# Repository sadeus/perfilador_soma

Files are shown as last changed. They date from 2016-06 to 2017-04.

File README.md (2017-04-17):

# Perfilador/Polarimetro SOMA

## Contenido
Se crearon sensores optomecánicos portátiles, para poder medir cambios de los haces de los setups del laboratorio. Todo el marco del proyecto SOMA

### Indice de carpetas
- software: Software para la adquisición y visualización de las mediciones. Acá se efectúa el análisis de los datos obtenidos
- firmware: Código para el uC para el polarimetro/perfilador. Tiene un makefila con los métodos usuales
- circuito: Diseño del circuito impreso
- perfilador: Diseño mecánico del perfilador
- polarimetro: Diseño mecánico del polarimetro
- espectrometro: Diseño del circuito para el espectrómetro (EN PROGRESO)

## Instalación

Para poder instalar y usar el software/firmware de este proyecto es necesario tener [NodeJS](https://nodejs.org/es/):

- Linux, macOS: Instalación por manejador de paquetes, [aquí](https://nodejs.org/es/download/package-manager/)
- Windows: Descargar binario de la página oficial

En una command prompt o terminal escribir lo siguiente para instalar dependencias

```npm install```

Esto instala las dependencias de firmware y software. Para obtener ayuda de los comandos disponibles ejecutar

```npm run```

### Lista de comandos
- `npm run ip`: abre el puerto serie creado al conectar el uC y obtiene la ip del dispositivo
- `npm run start`: inicia el servidor web del software de adquisición. Por defecto se entra en un browser en http://localhost:9000
- `npm run compile`: compila el firmware. Para compilar el firmware, por ahora, es necesario logearse con `npm run login` y una cuenta de [particle.io](http://build.particle.io)
- `npm run upload`: Actualiza el firmware del uC por USB. Es necesario tener el uC en modo DFU (ver [acá](https://docs.particle.io/guide/getting-started/modes/photon/#dfu-mode-device-firmware-upgrade-))

## Dependencias

### Software
- Python v3.5.0
- Numpy v1.11.3
- Pandas v0.19.2
- Matplotlib v2.0.0
- Scipy v0.18.1
- Flask v0.12
- Web browser (Firefox, Chrome, Safari, _no funciona en IE_)

### Firmware
Para compilar, flashear y escuchar el puerto Serie del uC es necesario tener:
- NodeJS v6.0
- Particle-cli v1.21.0
- readline-sync (para interfaz interactiva)

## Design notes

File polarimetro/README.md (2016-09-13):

# Polarímetro
## Proyecto SOMA

### Especificaciones

#### Mecánica
* Dimensiones: 
* Velocidad de adquisición: 10 mediciones/s
* Forma de fotodiodo: TO-5

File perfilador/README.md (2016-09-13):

# Perfilador de haz
## Proyecto SOMA

### Especificaciones
#### Mecánicas
* Dimensiones sin prolongación: 40x40x60 mm
* Dimensiones de prolongación: 50 mm desde centro del soporte, 8x20 mm 
* Diametro máximo de haz perfilable: 10 mm 
* Velocidad de adquisición: 40 perfiles/s
* Forma de fotodiodo: TO-5

#### Software embebido
* Microcontrolador: Particle Photon
    - STM32F205 120Mhz ARM Cortex M3
    - 1MB Flash
    - 128KB RAM
    - Broadcom BCM43362 Wi-Fi chip. 802.11b/g/n 2,4GHz
* Implementación en C++

#### Software PC
* Adquisición cada 1s de 40 perfiles
* Python v3.x
    - Numpy
    - Scipy
    - Matplotlib
    - PyQT

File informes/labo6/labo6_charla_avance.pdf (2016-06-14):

## Construcción de un perfilador de haz portátil automático

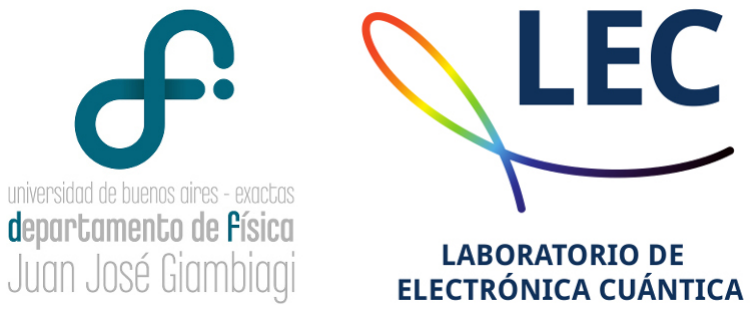
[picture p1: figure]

Estudiante: Sebastián Schiavinato Director: Dr. Hernán E. Grecco Codirectora: Dr. Andrea V. Bragas

Laboratorio 6, DF, FCEyN, UBA

Noviembre 19, 2015

## Objetivo del proyecto

Objetivos de laboratorio 6:
- Diseñar y construir un perfilador portátil y de fácil reproducción capaz de caracterizar el haz en diferentes setups ópticos.
- Diseñar y construir un espectrómetro portátil para aplicaciones del LEC, adaptado a los diferentes setups del laboratorio.

## Motivación del proyecto

Mucho es el tiempo desperdiciado en el laboratorio armado y desarmando el setup, alineando cada etapa.

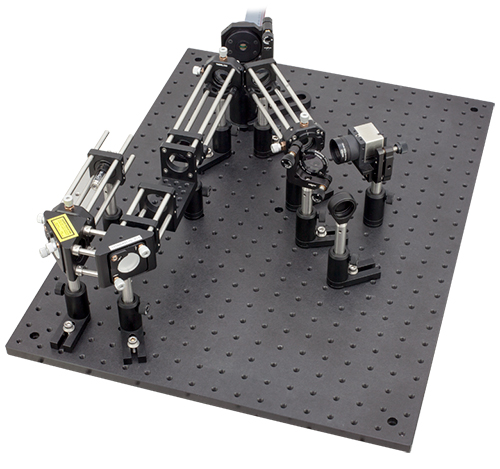
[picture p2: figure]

Caracterizar haces de fuentes con-lleva
- Perfil espacial. Divergencia
- Perfil espectral y temporal
- Polarización

## Concepto del perfilador

Funcionamiento general de un perfilador
- Se corta el haz con un filo móvil (en general con un
tornillo micrométrico),
recolectando el haz.
- Se usan sensores
económicos, integradores del haz obturado.

## Concepto del perfilador

Para haces gaussianos (la mayoría), el perfil de intensidades, es decir la integral del perfil, es la función error

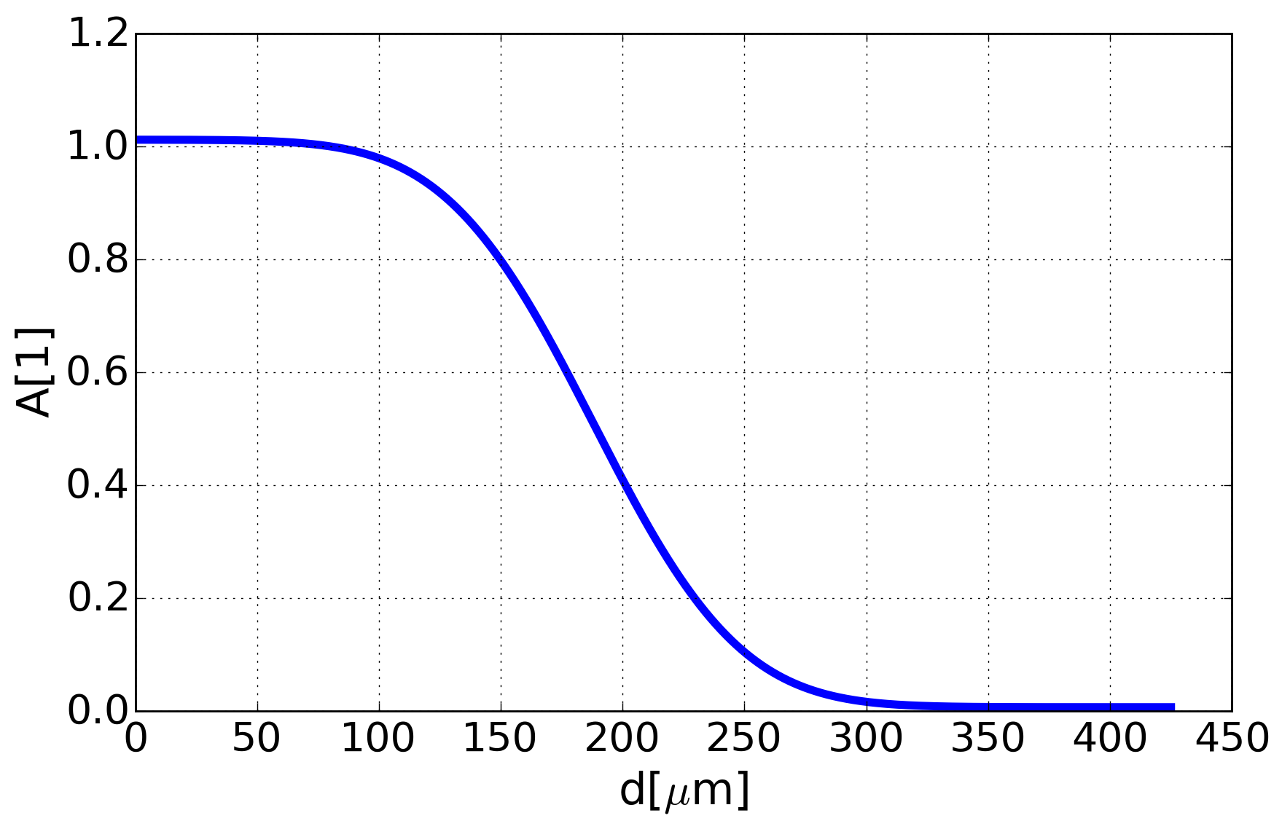
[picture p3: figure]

## Concepto del perfilador

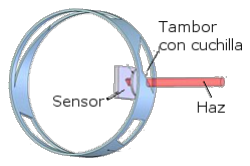
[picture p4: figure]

Propuesta inicial:
- Tambor giratorio, capaz de obturar automáticamente
- Sensor de luz integrador, tipo fotodiodo o medidor de potencia
- Adquisición en tiempo real de los cambios del haz.

## Diseño mecánico

Premisas mecánicas del perfilador:

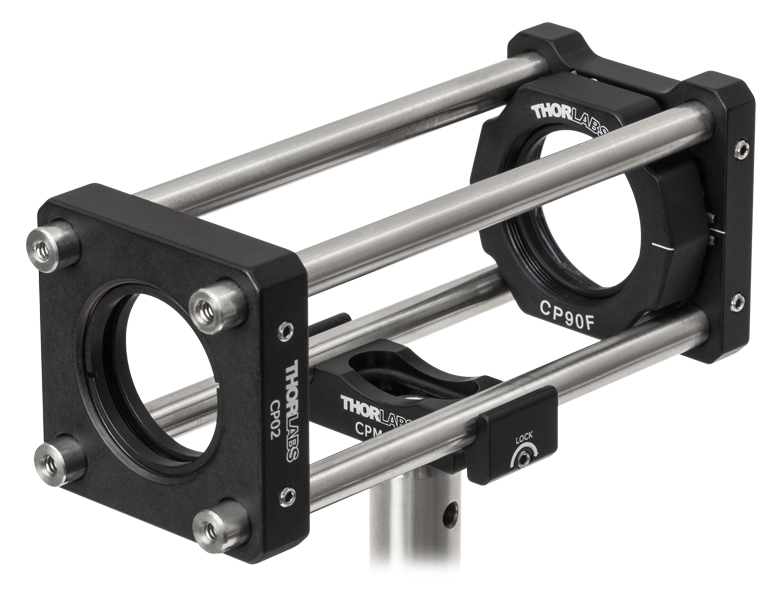
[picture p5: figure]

- Se debe poder insertar en el sistema Cage de ThorLabs, de 30mm. A 50mm de la mesa
- El tambor debe tener una velocidad que permita
actualización en tiempo real.

## Diseño mecánico

Diseño del tambor

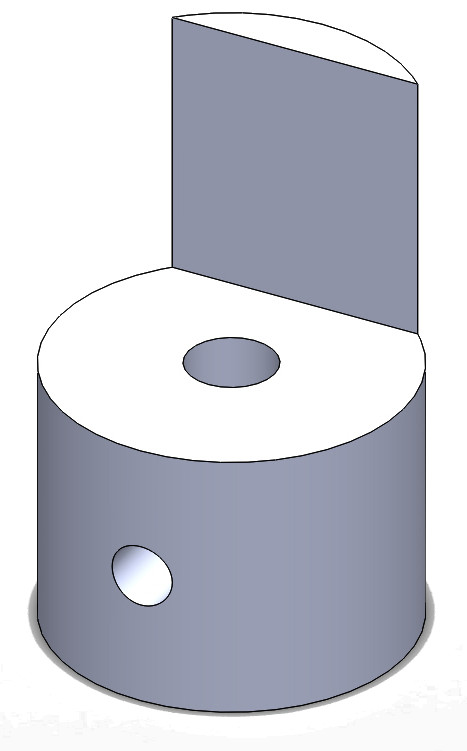
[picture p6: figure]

- Cilindro de 20mm de diametro
- Fácil de ubicar en el Cage
- Proyección axial, permite obturar el haz.
- Fácil prototipado con impresora 3D.

## Diseño mecánico

El motor se determinó con las siguientes premisas
- Debe ser fácil de controlar la velocidad. Descartados motores de escobillas, que requieren retroalimentación.
- Debe ser rápido, alcanzando 24 revoluciones por segundo si se puede. Descartado servomotores, no alcanzan las 2 revoluciones por segundo.
Se eligen motores paso a paso.
- Motor modelo NEMA 17 (1,8◦
, máx 3000PPS, 4kg cm).

## Diseño mecánico

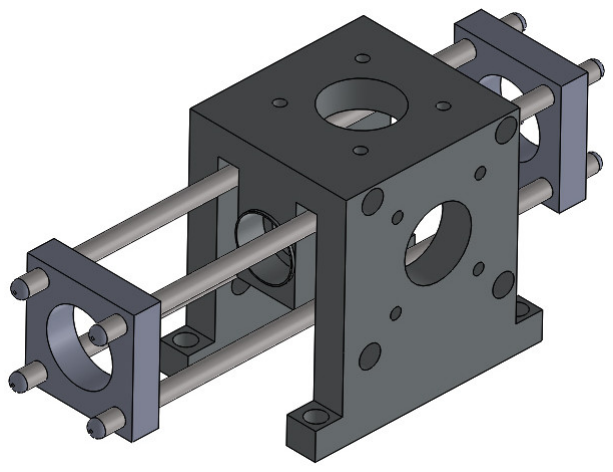
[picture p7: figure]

- Diseño auto-portante, no se necesita ningún agregado.
- Permite adaptarse al Cage y a otros entornos de trabajo.
- Permite medir el haz en
varias direcciones.

## Diseño de electrónica de adquisición

Electrónica digital (microcontrolador) de uso general, adaptada a la adquisición de un sensor de luz (fotodiodo)

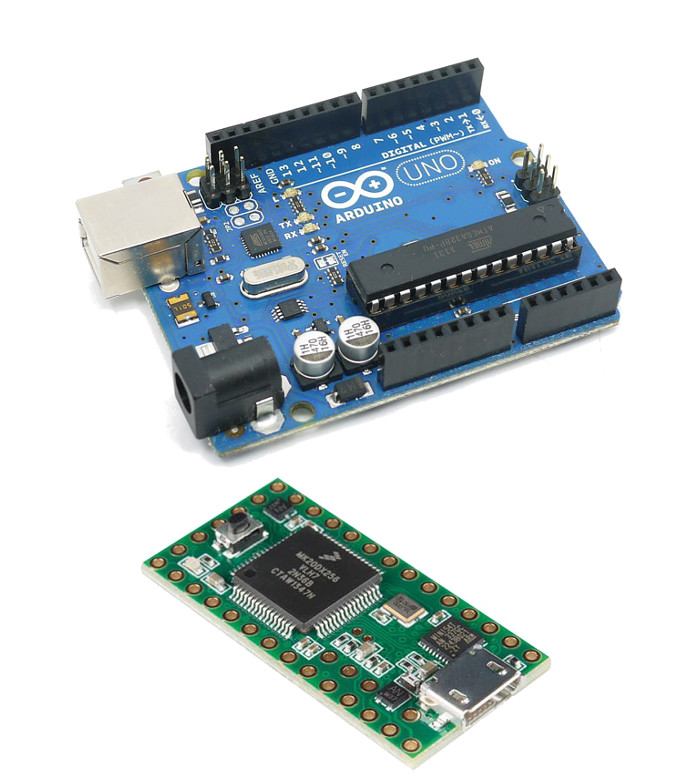
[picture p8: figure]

- Arduino UNO: Barato,
sencillo. CPU 16MHz y
2KiB RAM. ADC a 10ksps.
- Teensy v3.1: CPU 96MHz, y 64KiB RAM. ADC a 1Msps.
Tipicamente 100kmps.

## Diseño de electrónica de adquisición

Circuito resultante, con integrado driver (Pololu A4988) del motor

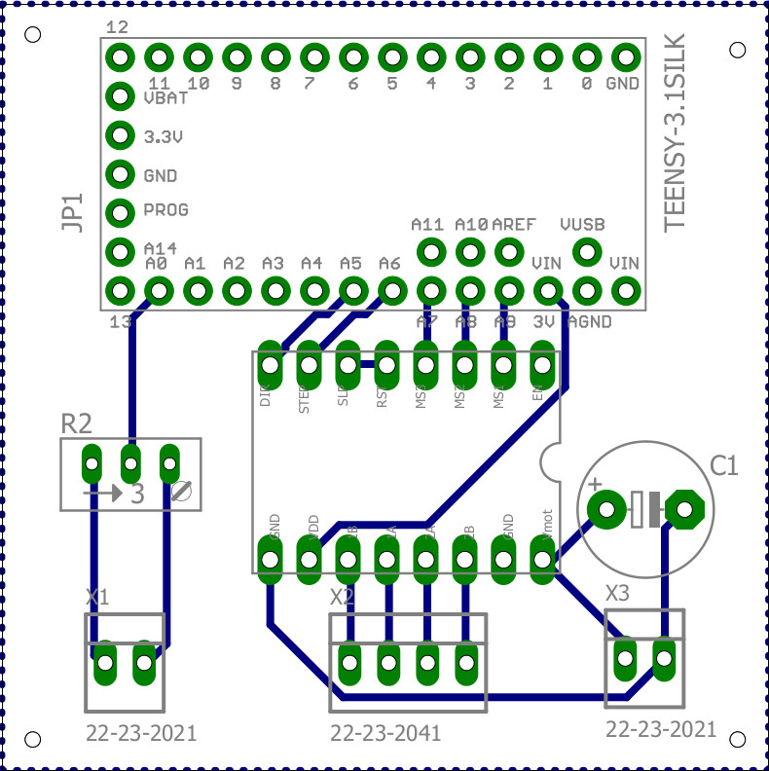
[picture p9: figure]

- Permite mover motores
hasta 2A por fase.
- Adquiere corriente del
fotodiodo en resistencia
variable por el usuario
- Adquiere 100ksps de la señal analogica.
- Permite adquirir a la
velocidad máxima de
12RPS, limitación del
motor, es decir adquirir
24 perfiles por segundo.

## Analisis de datos

La computadora es encargada del análisis automático de los datos transmitidos. A partir de una serie de datos

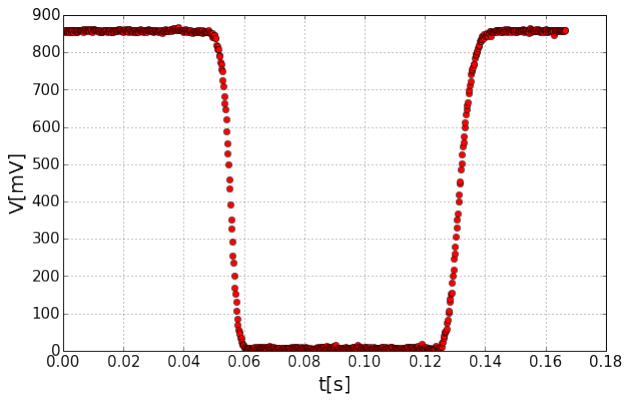
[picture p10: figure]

## Analisis de datos

Se ajusta automáticamente los datos con un algoritmo de procesamiento de señales propio.
- Tamaño del haz inferido del ajuste y la velocidad del
motor, con el error de
propagación
- Diferencia entre perfiles debido a problemas
mecánicos de la pieza
plástica.

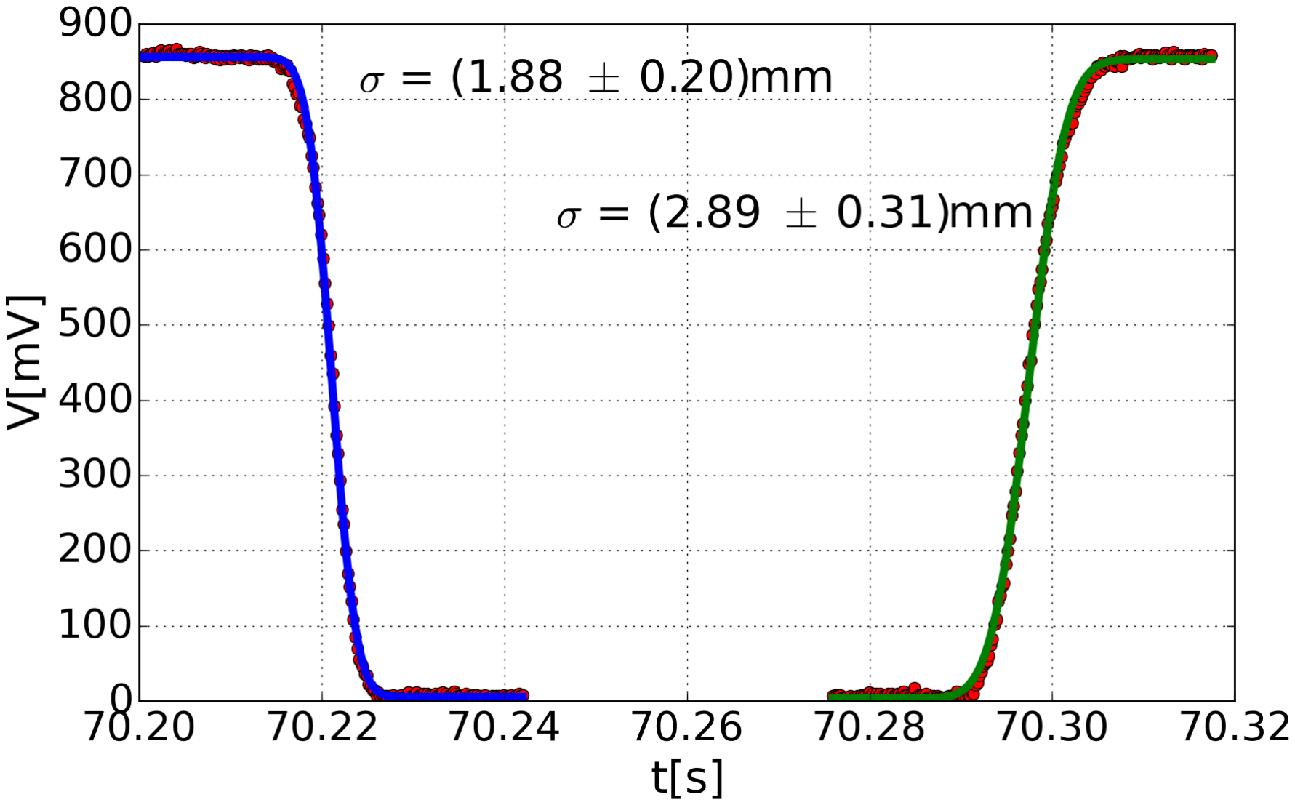
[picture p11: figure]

## Proyecto SOMA (Sistema de OptoMecánica Abierta)

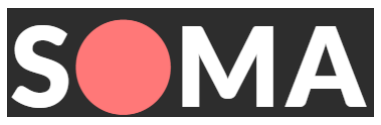
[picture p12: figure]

- Plataforma abierta de instrumental opto-mecánico
- Diseño con énfasis en la reproducibilidad, con tecnología de impresora 3D o mecanizado automático.
- Electrónica libre, controlada por software creado con tecnologías libres.

Página del proyecto: http://lec.df.uba.ar/soma

## A completar

- Mecanizado de las piezas metálicas
- Terminado final del perfilador
- Diseño y construcción del espectrómetro, a partir del circuito Hamammatsu C12666MA

## Objetivos de Laboratorio 7

Estos dispositivos van a ser utilizados durante laboratorio 7 en los siguientes proyectos:
- Mejora de la resolución del SPIM mediante la optimización del perfil del haz
- Caracterización del espectro de emisión de nanolamparas de Lantánidos

# Gracias

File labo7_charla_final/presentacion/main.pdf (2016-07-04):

## Determinación de características ópticas del SPIM para la medición de anisotropía de muestras biológicas


Estudiante: Sebastián Schiavinato Director: Dr. Hernán E. Grecco Codirectora: Dr. Andrea V. Bragas

Laboratorio 6 y 7, DF, FCEyN, UBA

Julio 5, 2016

## Motivación del proyecto

En el Laboratorio de Electrónica Cuántica (LEC) se dispone de un microscopio SPIM

- Utiliza muestras con fluoroforos
- Con una hoja de luz
(lightsheet) ilumina un plano de la muestra por vez
- Disminuye el photobleaching (blanqueo de los flouroforos)
- Permite recostruir una imagen en 3D de la muestra

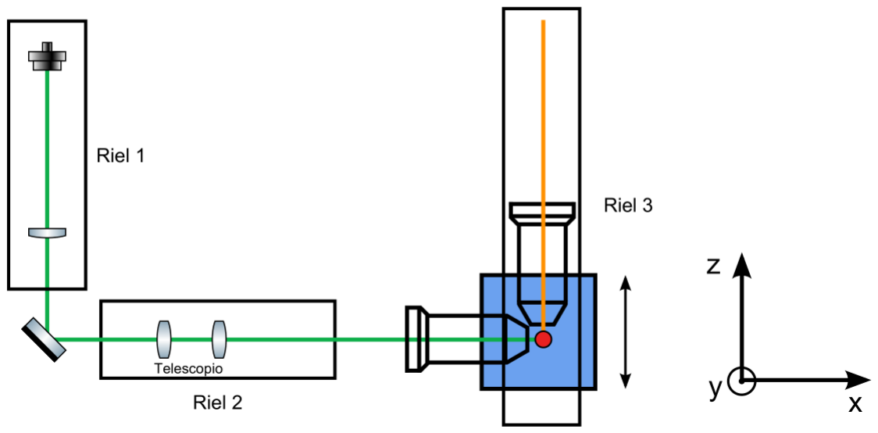
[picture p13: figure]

## Motivación del proyecto

La construcción de este microscopio requiere determinar

- Perfil del haz, que cambia el
tamaño de la hoja del haz
- Espectro del haz, determina los flouroforos a utilizar
- Polarización del haz, que si es lineal permite hacer mediciones
de anisotropía de los fluoroforos

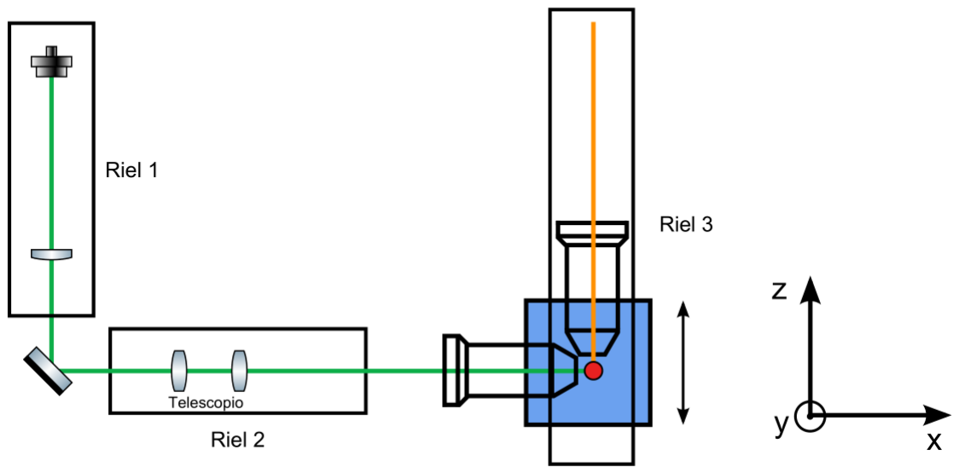
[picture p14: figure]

Para calibrar el SPIM,se construyó el siguiente instrumental portátil
- Perfilador
- Polarimetro

## Concepto del perfilador

- Determinar el perfil especial del haz en un plano
- Al desplazarse permite
determina la divergencia del haz.
- Perfiladores con cámaras CCD. Sensores muy caros
- Perfiladores integradores. Complejidad mecánica

## Concepto del perfilador

Para haces gaussianos (la mayoría), el perfil de intensidades, es decir la integral del perfil, es la función error


## Concepto del polarizador

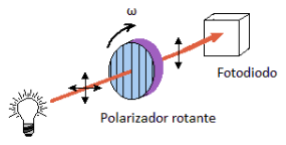
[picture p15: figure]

- Permite determinar eje mayor y eje menor de polarización eliptica.
- Permite identificar polarización circular.
- Depende de la precisión de rotación del motor, pero puede mejorarse con mecánica adecuada.

## Concepto del polarizador

Ley de Malus

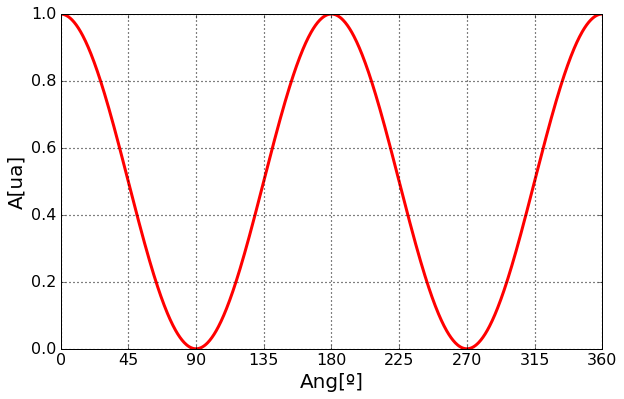
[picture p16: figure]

α =

máx − mín
máx + mín =

1 | si lineal
0 | si circular
(0, 1) si eliptica

## Perfilador en Laboratorio 6

Piezas mecánicas del perfilador

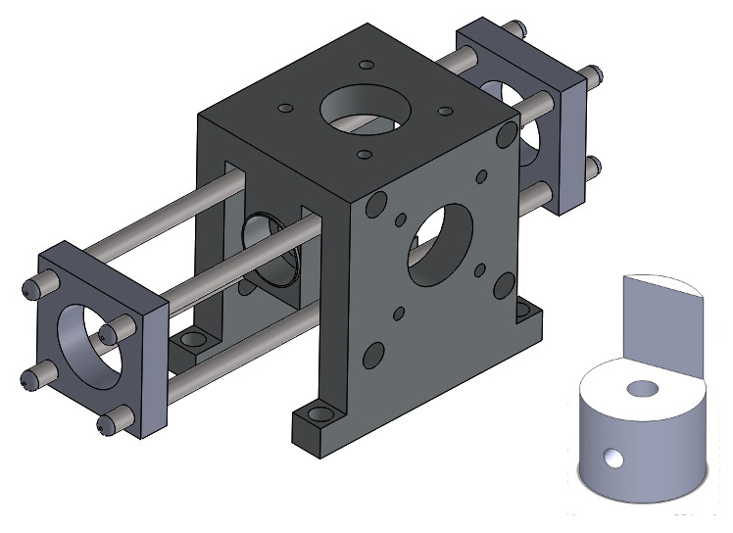
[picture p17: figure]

- Diseño autoportante.
- Tambor de perfilación permite medir en sistema Cage de
Thorlabs. Permite medir
divergencias importantes
- Tambor impreso en 3D.
- Motor paso a paso NEMA 17. 200 pasos por vuelta. Máximo 15rps.

## Perfilador en Laboratorio 6

Electrónica de adquisición

- uC Teensy v3.2. CPU 96MHz, y 64KiB RAM. ADC 1Msps max.
- Pololu A4988. Motores hasta 1.5A por fase
- Buffer de puerto serie de 1200 datos
- Software de ajuste en continuo cambio. Hecho en Python
- Máxima adquisición de 12 perfiles por segundo, limitación del uC/Software.


## Mediciones de calibración

Mediciones de calibración

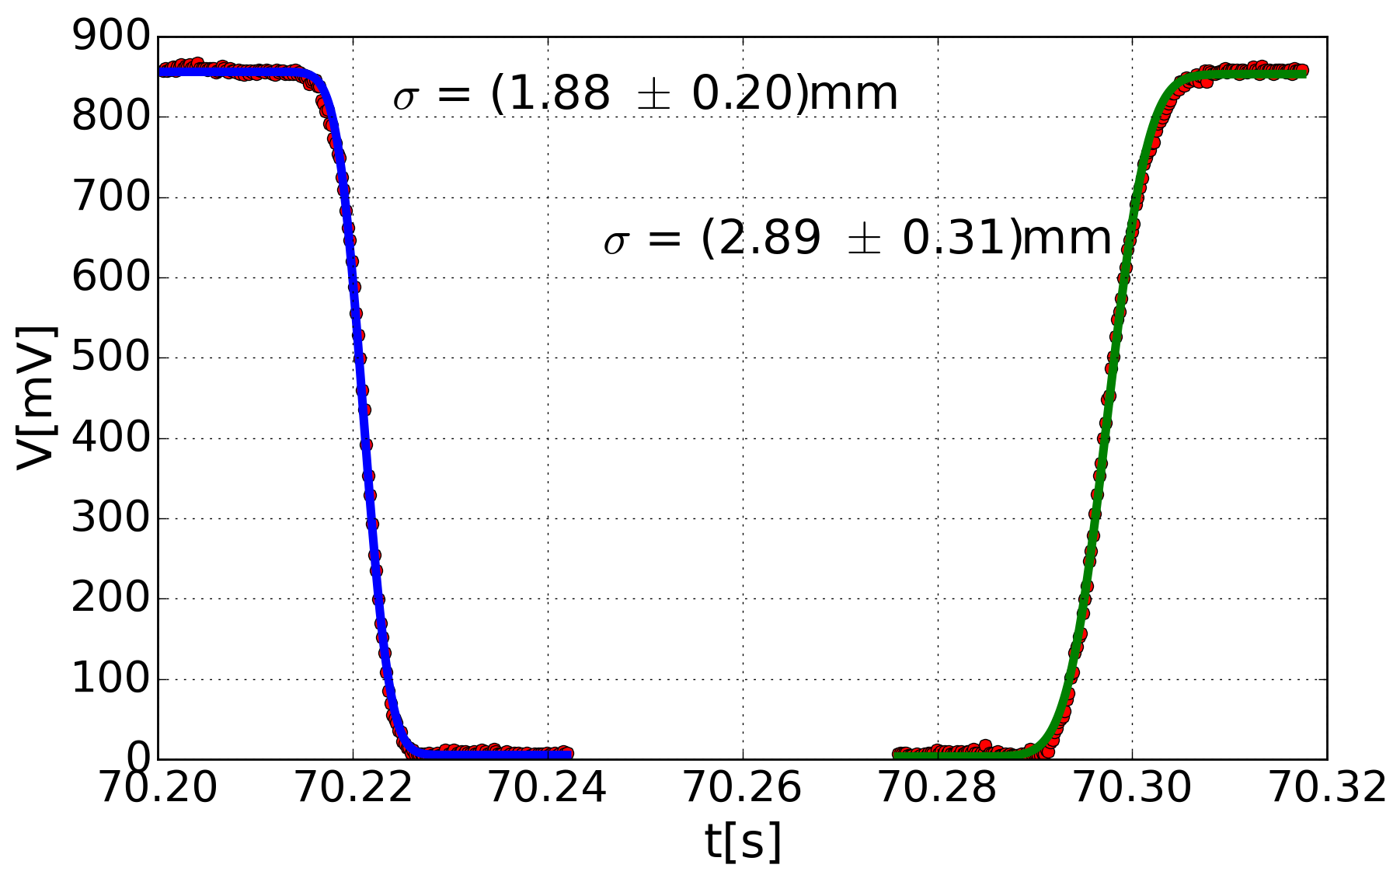
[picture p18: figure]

- Medición a salida de
colimador F220FC.
- Diferencia apreciable de tamaño de haz entre
transiciones.
- Es de origen mecánico,
soporte no ajusta
correctamente el motor

## Mediciones de calibración

Mediciones de calibración

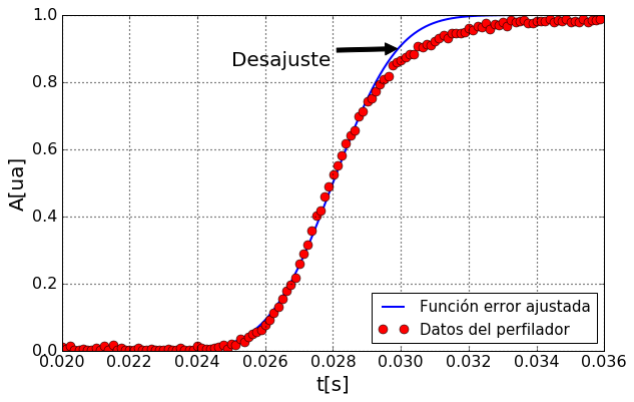
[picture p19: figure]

- Desajuste entre función error y datos al
desobturar haz.
- Fotodiodo con
resistencia de carga
enorme genera respuesta
en frecuencia pobre.
- Es necesario amplificar
señal del fotodiodo

## Perfilador en Laboratorio 7

Primera iteración mecánica

- Soporte adosable a la
mesa óptica por perros.
Facil colocación
- Motor encastrado en
soporte. No hay
artefactos mecánicos
- Tambor de metal con
superficie no reflectante
- No permite medir
fácilmente en el otro eje. Habrá otra iteración

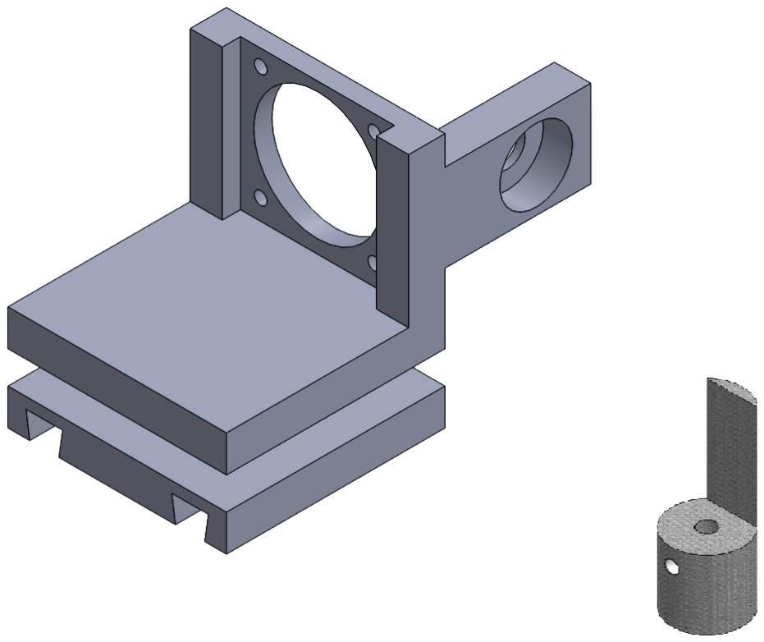
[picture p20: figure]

## Perfilador en Laboratorio 7

Segunda iteración mecánica.

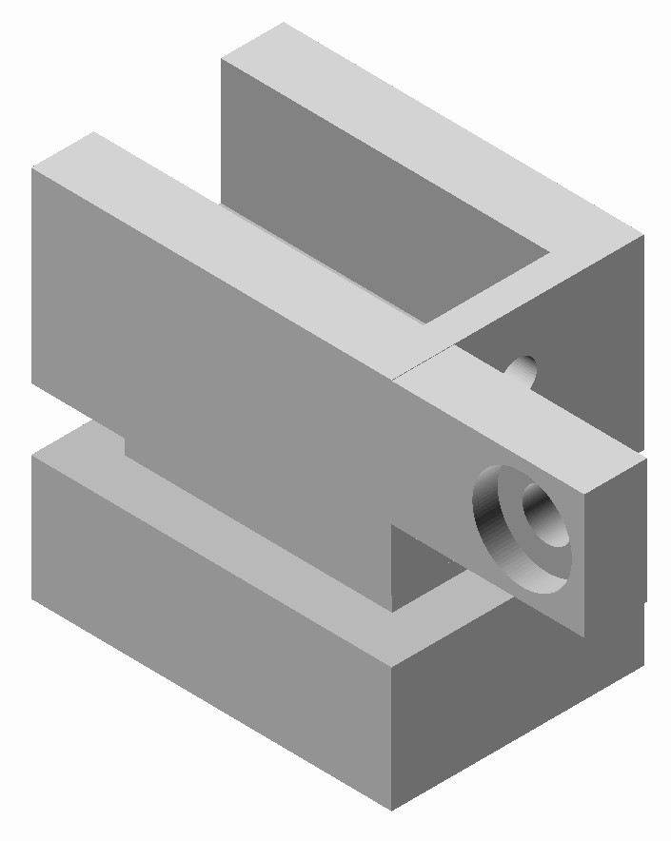
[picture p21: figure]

- Motor NEMA 8, reduce un
500 % el tamaño.
- Soporte fácil de colocar sobre la mesa óptica y sobre un soporte en altura
- Tambor reimpreso en plástico

## Mecánica del polarimetro

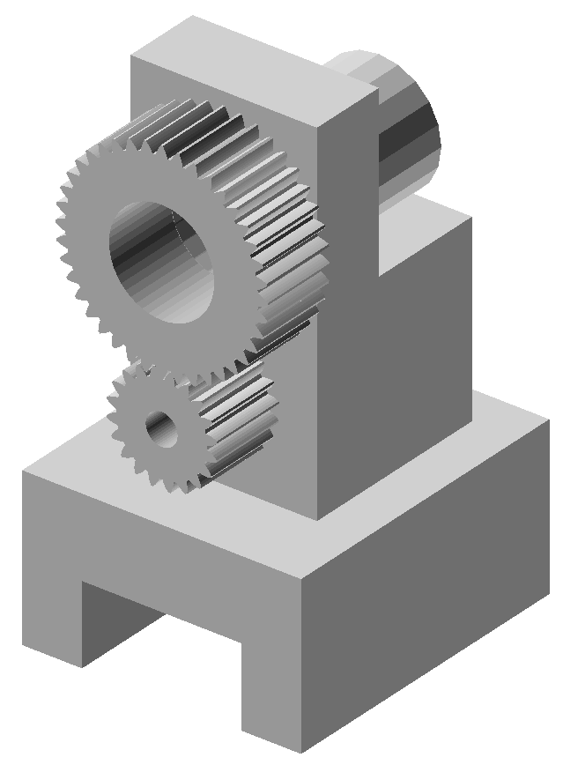
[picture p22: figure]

- Motor NEMA 8 mueve el
engranaje inferior paso a paso
- Utiliza electrónica creada para el perfilador. Mide en cada paso del motor
- Hecho con impresión 3D en plástico

## Electrónica de adquisición

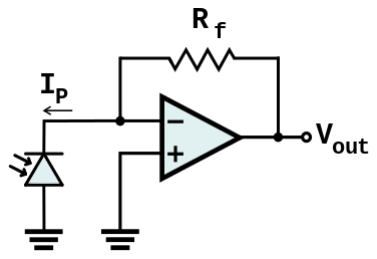
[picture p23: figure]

- Se mide con amplificador de corriente Standford SR750 y se observa mejoras substanciales
- Implementado amplificador de transimpedancia con fotodiodo no polarizado.
- Mejor respuesta en frecuencia y ajusta correctamente una
función error.

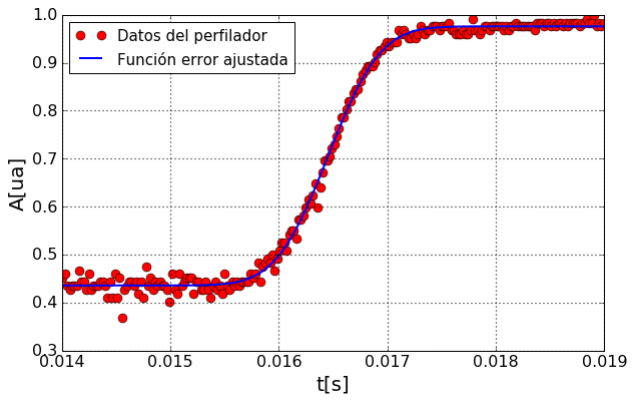
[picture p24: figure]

## Calibración de amplificador


- Amplificador con LM358.
Con fuente simple
- Respuesta al escalón de 0,4V µs

−1
. 4 veces más
grande de la necesaria
- Rango lineal bastnate
amplio, pero no acusa
corriente nula. Se puede
buscar otro amplificador.
Suficiente para la
amplicación

## Generación de sensores portátiles


Spark Photon
- ARM Cortex M3 120MHz con stack WiFi.
- 128KiB RAM y 1MiB FLASH
- Programación en la nube, permite actualizaciones OTA.
- API de programación más poderosa. C++ por defecto
- Software implementado con licencia libre, puede ser
adaptado

## Generación de sensores portátiles

Resultados con este uC/Software


- Se pudo mover el motor hasta 30RPS. PWM mejor implementado
- Adquisición de datos (del uC) cada 10µs o 100ksps. Más de lo necesario
- Conexión TCP ya resuelta, cada 0,1s se obtiene 4000 datos.
- Software de adquisición hecho enteramente en Python, libre, con interfaz de usuario gráfica

## Mediciones con el perfilador


Calibración del instrumento, medición del colimador F280FC del SPIM

- Inicio del riel:
σ = (3, 03 ± 0, 15) mm
- Fin del riel:
σ = (3, 02 ± 0, 18) mm

## Mediciones con el perfilador

Medición manual del colimador F280FC del SPIM


## Mediciones con el perfilador


Haz en el telescopio del SPIM

Medición a
d≈80 mm del fin del telescopio σ1 = (0, 55 ± 0, 02) mm
σ2 = (2, 11 ± 0, 05) mm

## Mediciones con el polarimetro

Calibración de láminas polarizadoras

- Con dos polarizadores móviles se puede terminar los
parámetros del material
polarizador
- El plástico usado tiene la siguiente matriz de transmisión
0, 5 | 0
0 | 2 × 10⁻⁶


- Permite polarizar, pero elimina un %50 de la señal en el
máximo.

## Mediciones con el polarimetro


Medición de polarización par láser azul DHOM-M-473 Antes de la fibra óptica

máx − mín
máx + mín = (0,83 ± 0,39)

Después de la fibra óptica

máx − mín
máx + mín = (0,83 ± 0,31)

## Conclusiones

Del polarizador
- El perfilador mide exitosamente el haz, con un error del %5, comparable con la medición manual
- Se pudo caracterizar el haz a salir de la fibra y en el telescopio correctamente
- El perfilador fue capaz de medir la divergencia
con solo un set de mediciones.
- Para medir la salida del telescopio habrá que diseñar un perfilador más compacto.

## Conclusiones

Del polarimetro
- La lámina polarizadora utilizada está lejos de ser un polarizador perfecto, pero es funcional a la aplicación
- Se midió la polarización antes de acoplar en fibra y después de acoplar en fibra y no se observó cambio de polarización
- Esta medición es de importancia fundamental para medir anisotropía de flouroforos en el SPIM

## Proyecto SOMA (Sistema de OptoMecánica Abierta)


- Plataforma abierta de instrumental opto-mecánico
- Diseño con énfasis en la reproducibilidad, con tecnología de impresora 3D o mecanizado automático.
- Electrónica libre, controlada por software creado con tecnologías libres.

Página del proyecto: http://lec.df.uba.ar/soma

# Gracias

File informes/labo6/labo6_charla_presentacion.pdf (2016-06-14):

## Construcción de instrumental optomecánico portatil


Sebastián Schiavinato

Laboratorio 6, DF, FCEyN, UBA

September 15, 2015

## SPIM (Single Plane Ilumination Microscope)


- Se crea un haz en forma de hoja (lightsheet).
- El objetivo del microscopio está a 90◦
- Moviendo la muestra
(sumergida en agua) se
activan diversos planos de fluoforos y se reconstruye la imagen en 3D de la muestra.

## Problemas, Caraterización

Caracterizar un haz de luz conlleva

- Perfil espacial
- Divergencia
- Perfil espectral y temporal
- Polarización


Mucho es el tiempo desperdiciado en el laboratorio armado y desarmando el setup, alineando cada etapa.

## Objetivos

El objetivo de este trabajo de Laboratorio 6 es diseñar y construir un perfilador y un espectrómetro portátil y de pequeñas dimensiones, que permita utilizarlos de forma rápida en los setups usuales del LEC y de los laboratorios de óptica.


## Perfilador

Funcionamiento general de un perfilador
- Se corta el haz paso a paso, recolectando el haz.
- Sensores más económicos.


Propuesta de este laboratorio:
- Tambor giratorio con
ranuras.
- Adquisición en tiempo real de los cambios del haz.

## Espectrometro


- Separación de luz en el plano del CMOS lineal
- Serialización de señal captada por el CMOS integrada

## Proyecto SOMA (Sistema de OptoMecánica Abierta)


- Plataforma abierta de instrumental opto-mecánico
- Diseño con énfasis en la reproducibilidad, con tecnología de impresora 3D o mecanizado automático.
- Electrónica libre (Arduino), controlada por software creado con tecnologías libres.

Página del proyecto: http://lec.df.uba.ar/soma

## Objetivos a futuro, Laboratorio 7

Estos dispositivos van a ser utilizados durante laboratorio 7 en los siguientes proyectos:
- Mejora de la resolución del SPIM mediante la optimización del perfil del haz
- Caracterización del espectro de emisión de nanolamparas de Lantánidos

## Factibilidad

- Diseño reproducible de forma simple para cualquier laboratorio
- Electrónica y sistema de adquisición de datos libres.
- Extensa documentación y experiencia en el laboratorio.
- Financiamiento por proyecto ANPCyT PICT-2013-1301

# Gracias

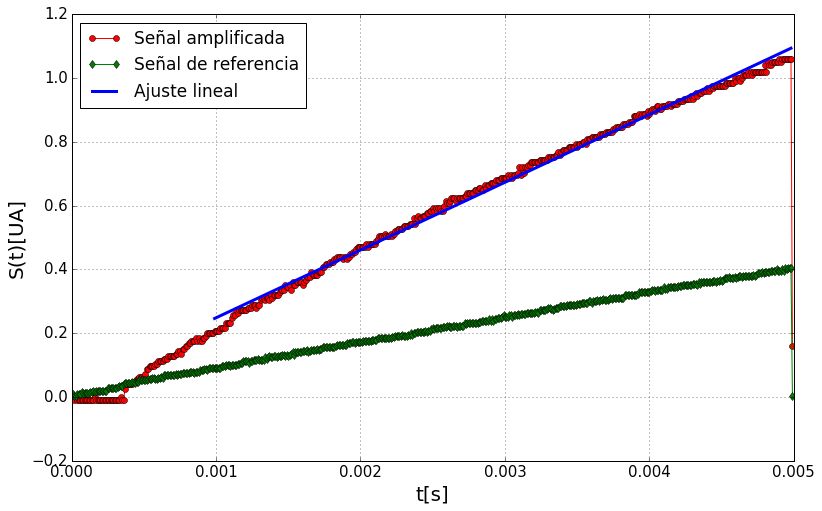
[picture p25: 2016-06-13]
circuito/design/analisis_amp/analisis/lin_amp.png

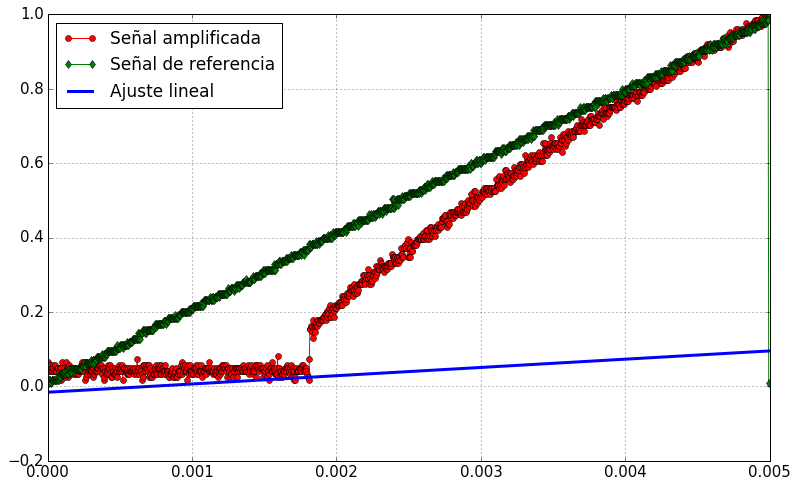
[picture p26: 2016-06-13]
circuito/design/analisis_amp/analisis/led_rojo_rampa_offset.png

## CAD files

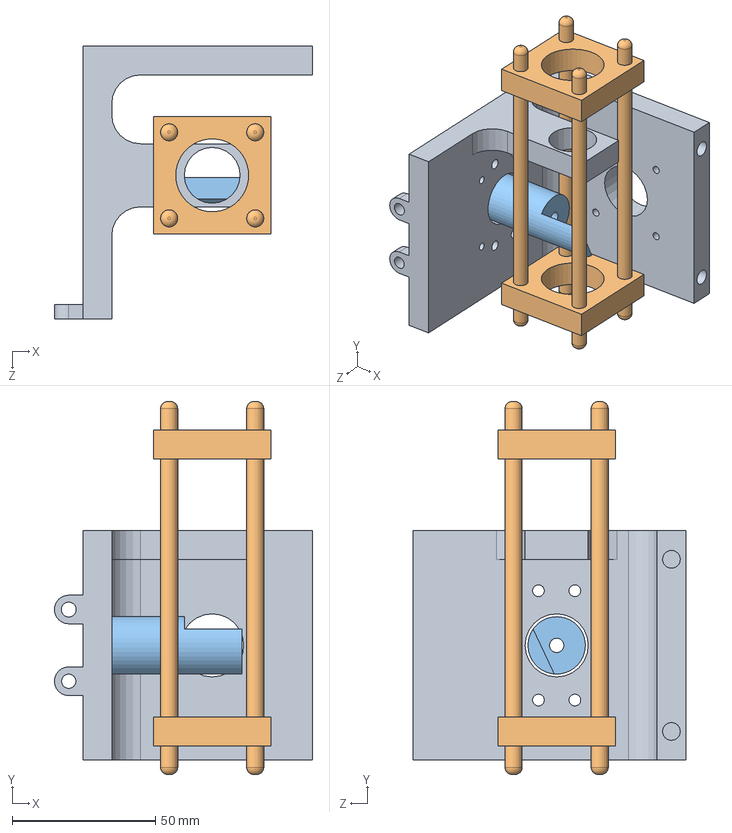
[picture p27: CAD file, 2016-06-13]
perfilador/mecanica/nema17/ensamblaje.SLDASM
90.0 x 130.0 x 95.0 mm
soporte_v2
cage
tambor_v2

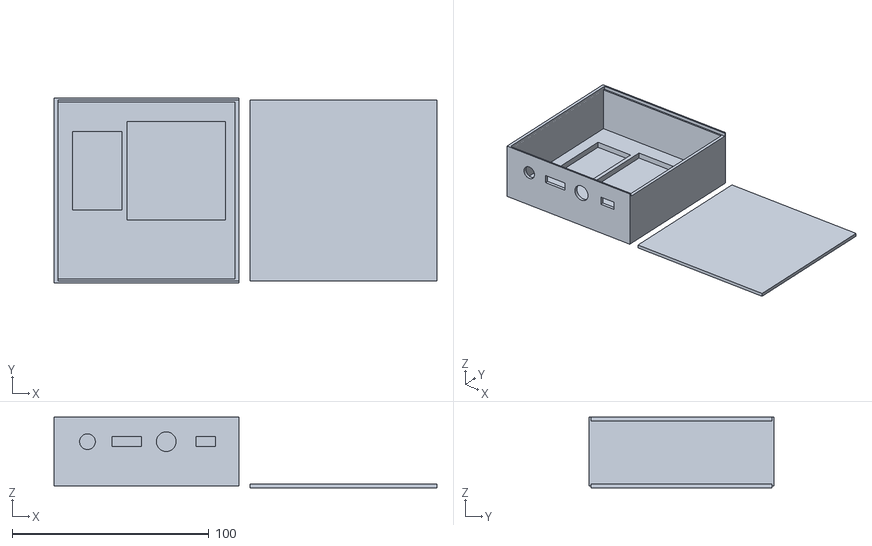
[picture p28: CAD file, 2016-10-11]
circuito/carcasa.stl
194.5 x 94.0 x 36.0

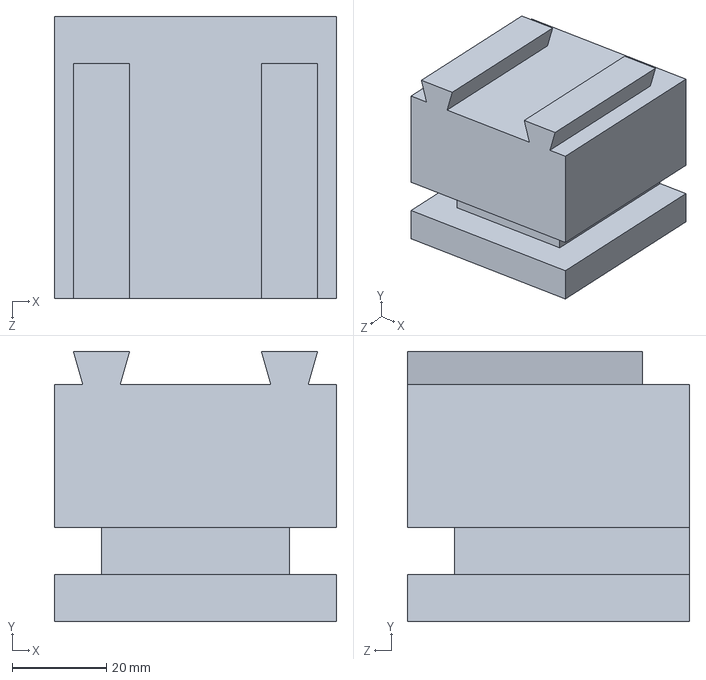
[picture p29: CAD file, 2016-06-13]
perfilador/mecanica/nema17/encastre/soporte_base_50_5.SLDPRT
60.0 x 57.5 x 60.0 mm

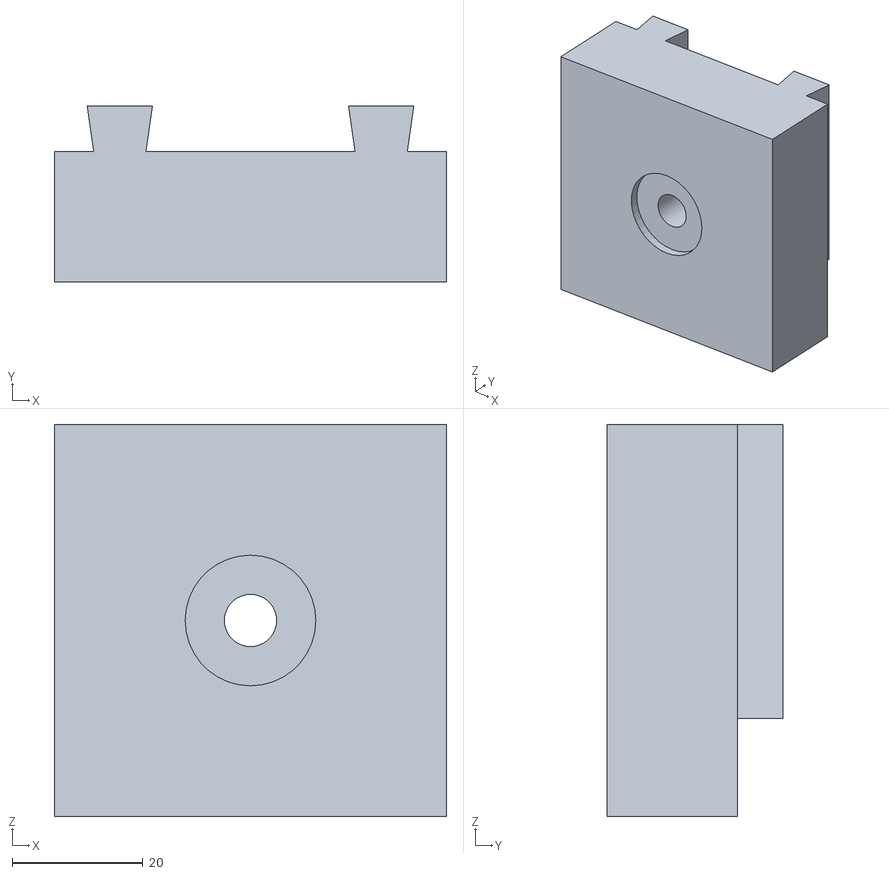
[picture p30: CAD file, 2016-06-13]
perfilador/mecanica/nema17/soporte/soporte_base_poste.stl
60.0 x 27.0 x 60.0

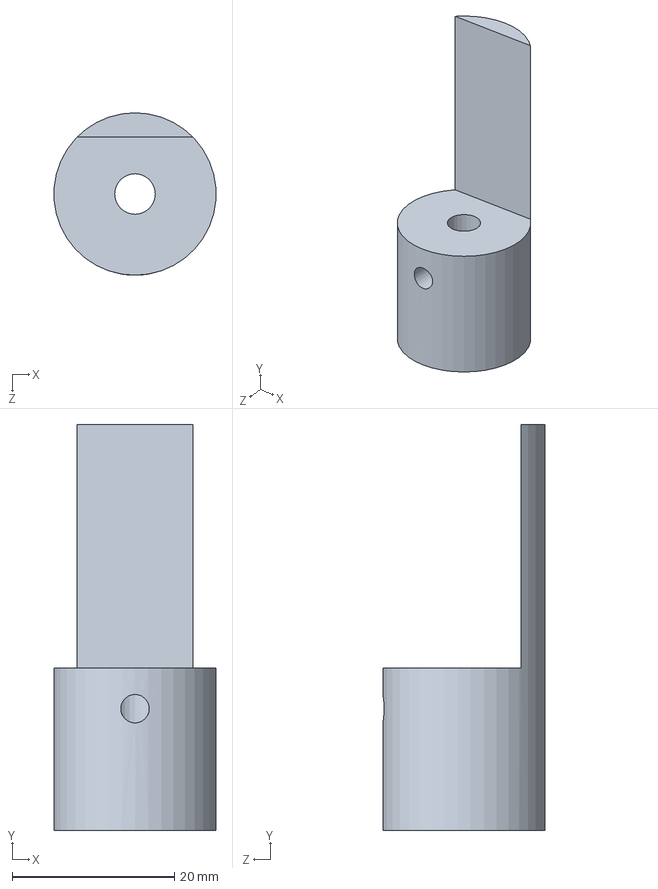
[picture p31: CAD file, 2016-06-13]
perfilador/mecanica/nema17/tambor/tambor_v3.sldprt
19.9 x 50.0 x 20.0 mm

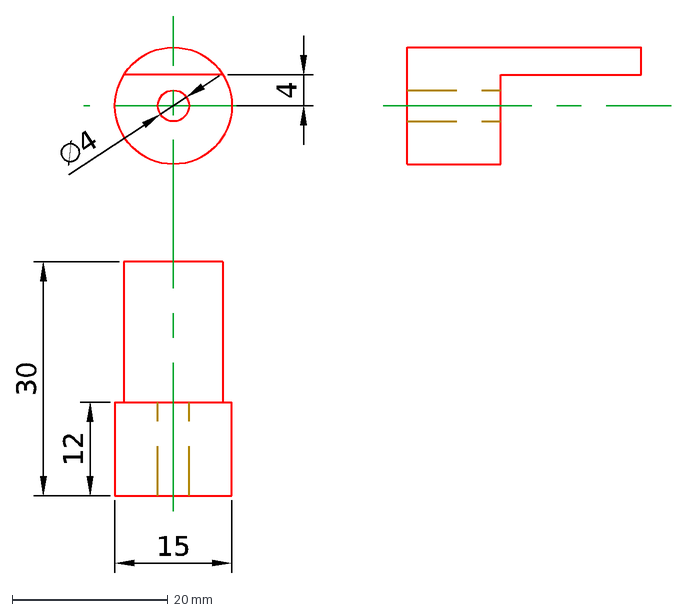
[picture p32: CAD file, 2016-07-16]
perfilador/mecanica/nema8/tambor_perfilador.dxf
15
30
12
4
∅4

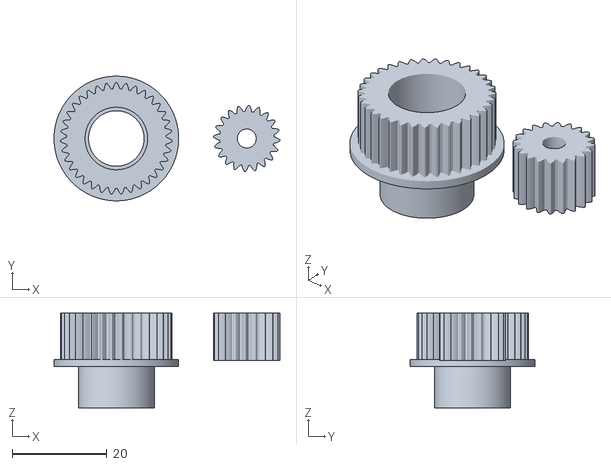
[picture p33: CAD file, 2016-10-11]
polarimetro/design/engranajes.stl
47.6 x 26.3 x 20.0

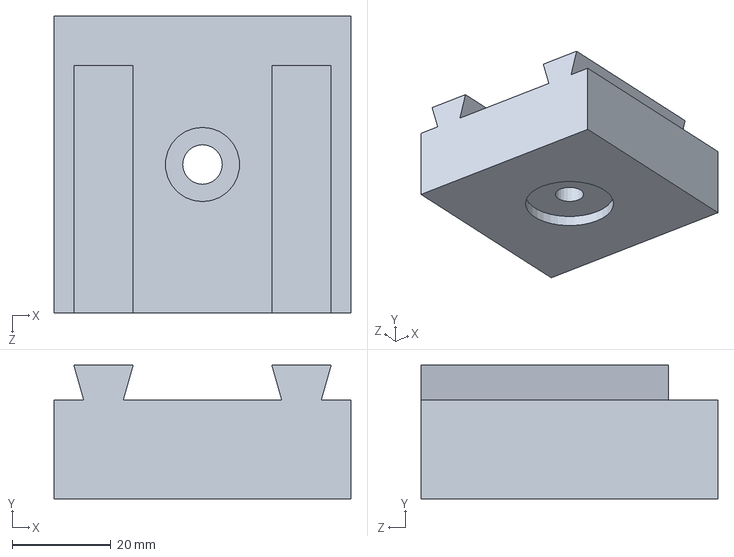
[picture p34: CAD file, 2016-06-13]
perfilador/mecanica/nema17/encastre/soporte_base_poste.SLDPRT
60.0 x 27.0 x 60.0 mm

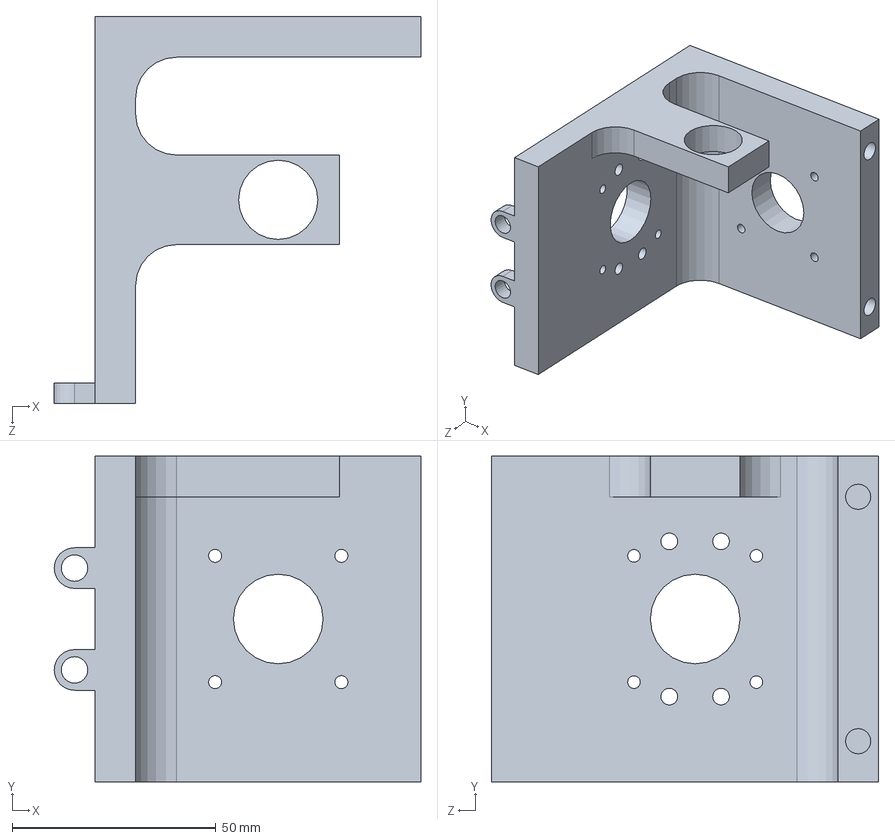
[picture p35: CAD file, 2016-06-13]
perfilador/mecanica/nema17/soporte/soporte_v2.sldprt
90.0 x 80.0 x 95.0 mm

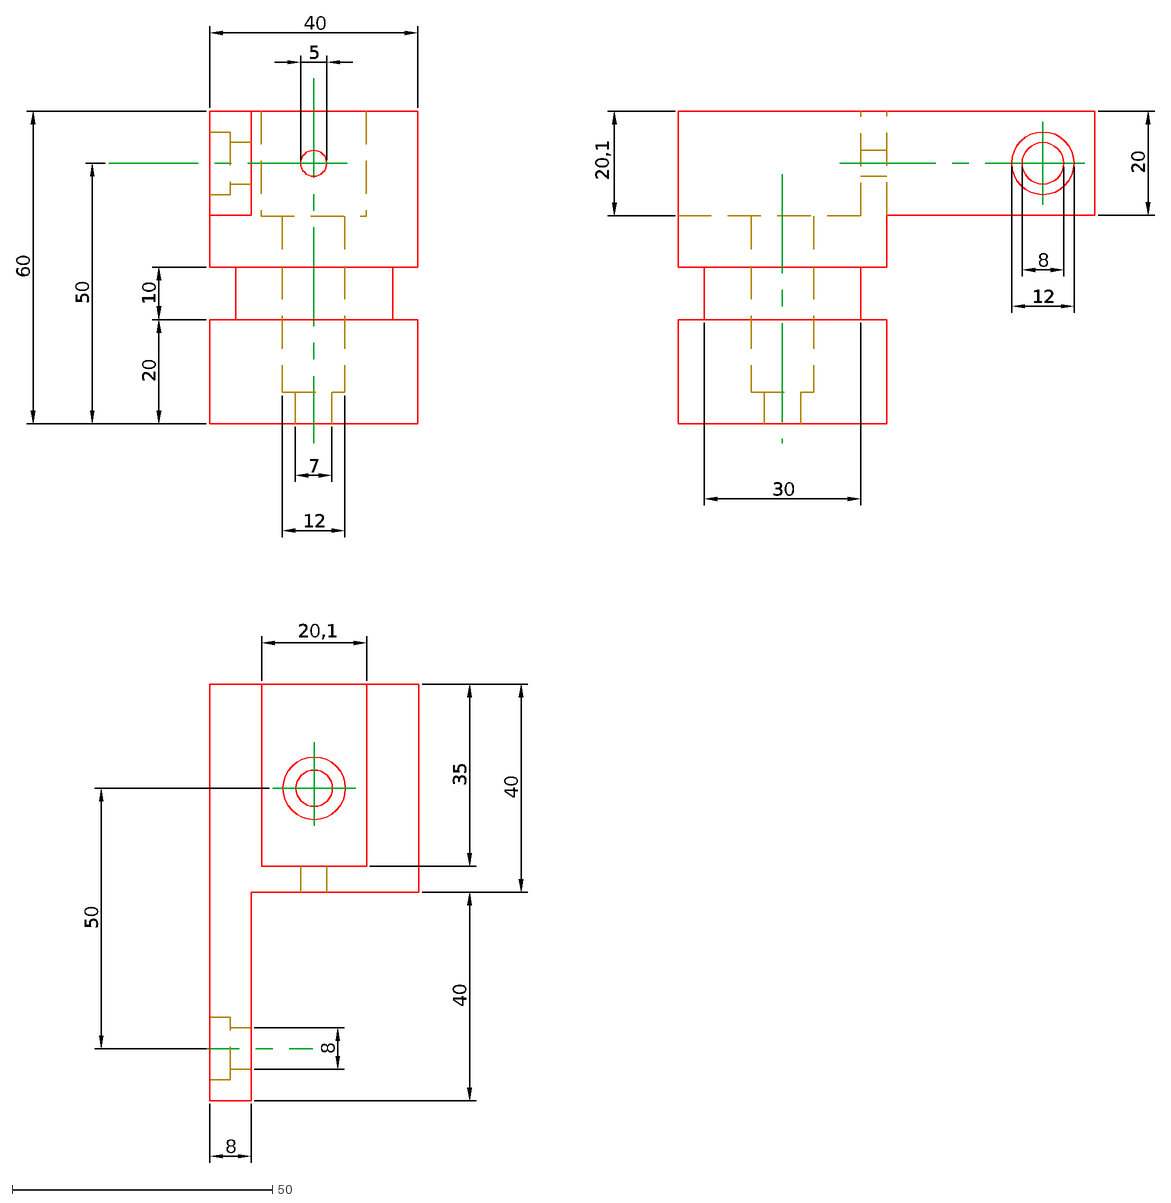
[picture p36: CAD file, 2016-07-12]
perfilador/mecanica/nema8/soporte_perfilador.dxf
10
20
60
40
7
12
8
50
20,1
35
30
5

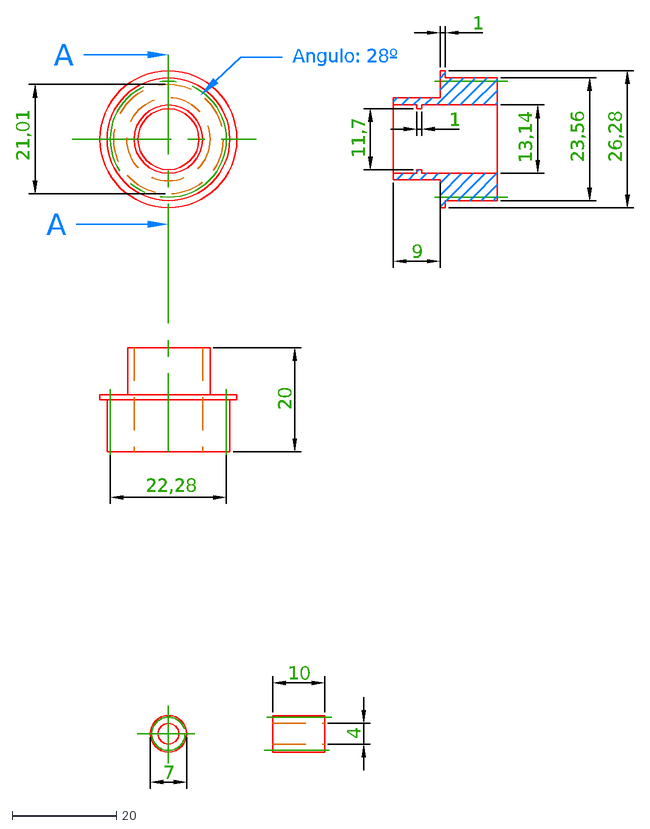
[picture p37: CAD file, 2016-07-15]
polarimetro/design/engranaje_mayor_polarimetro.dxf
A
23,56
13,14
11,7
1
26,28
9
22,28
20
21,01
Angulo: 28º
4
10
7

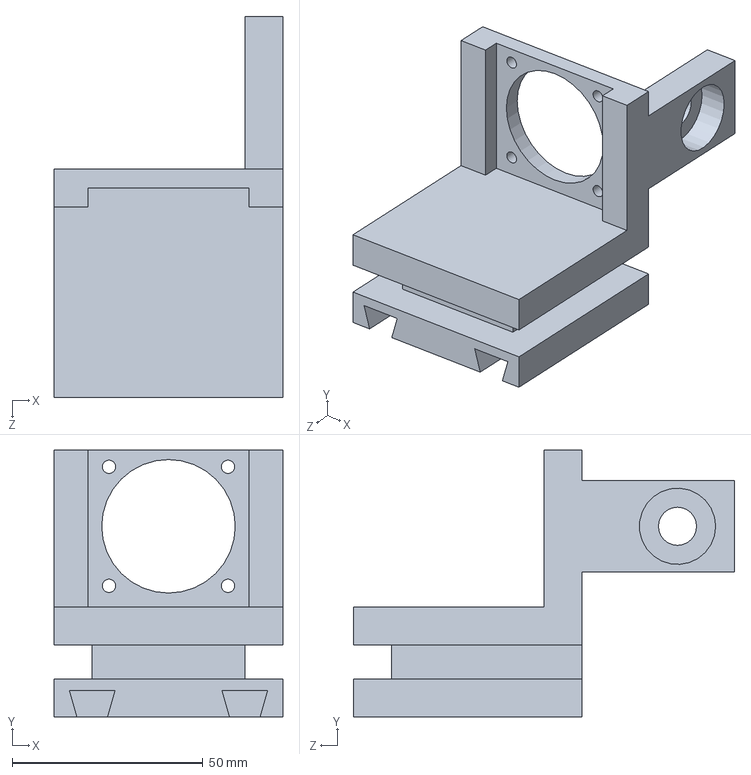
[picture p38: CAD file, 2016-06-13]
perfilador/mecanica/nema17/encastre/soporte_ph.SLDPRT
60.0 x 70.0 x 100.0 mm

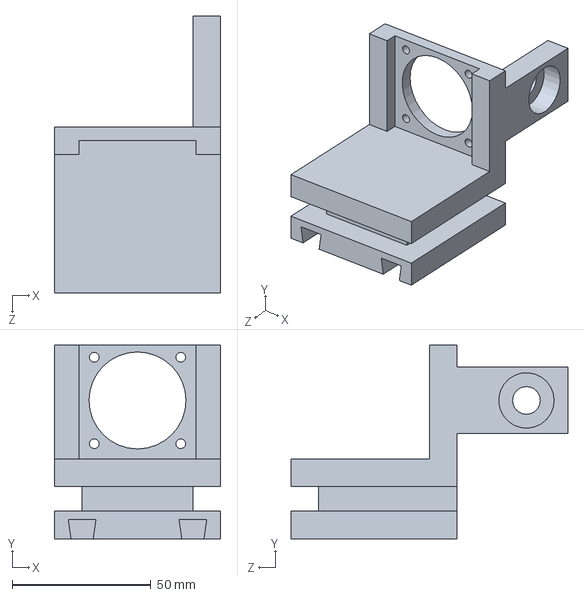
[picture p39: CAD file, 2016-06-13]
perfilador/mecanica/nema17/soporte/soporte_perros.sldprt
60.0 x 70.0 x 100.0 mm

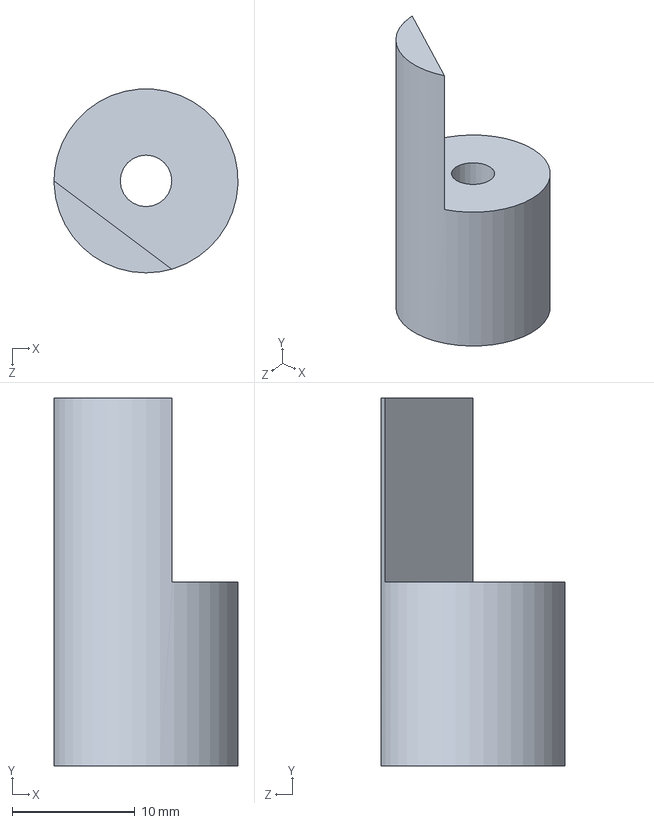
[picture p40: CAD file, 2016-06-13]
perfilador/mecanica/nema17/tambor/media_cania.sldprt
15.0 x 30.0 x 15.0 mm

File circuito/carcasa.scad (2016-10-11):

sizeHueco = [90, 90 , 35];

sizeTapa = sizeHueco - [0, 0, sizeHueco[2]] + [5,2,2];

$fn=50;

translate([0,0,sizeHueco[2]/2]){
    difference(){
        
        //Carcasa exterior
        cube(sizeHueco + 4 * [1, 1, 0], center=true);
        
        //Hueco
        translate([0,0,6]){
            cube(sizeHueco, center=true);
        }
        
        //Circuito
        translate([15,10,-10]){
            cube([50,50,10], center = true);
        }

        //Regulador
        translate([-25,10,-10]){
            cube([25,40,10], center = true);
        }

        
        //BNC fotodiodo
        translate([10,-sizeHueco[1]/2,5]){
            rotate([90,0,0]){
                cylinder(d=10,h=20,center=true);
            }
        }
        
        //Jack tensión
        translate([-30,-sizeHueco[1]/2,5]){
            rotate([90,0,0]){
                cylinder(d=8,h=20,center=true);
            }
        }
        
        //Cable plano de motor
         translate([-10,-sizeHueco[1]/2,5]){
            cube([15,8,5], center=true);
        }
        
        //USB
         translate([30,-sizeHueco[1]/2,5]){
            cube([10,10,5], center=true);
        }
        
        //Agujero de tapa
        translate([2.5,0,sizeHueco[2]/2 - 1]){
            cube(sizeTapa + [0.1,0.1,0.1], center = true);
        }
        
        
    }

}


//Tapa
translate([100,0,0]){
    cube(sizeTapa, center = true);
   
}

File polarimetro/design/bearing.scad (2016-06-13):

function radius_to_balls(r_ball, r) = 180 / asin(r_ball / r);
function ball_to_radius(n, r) = r * sin(180 / n);

module Bearing(outer, inner, attempt, gap, hole, height) {
	n = round(radius_to_balls(attempt, inner));
	r = ball_to_radius(n, inner);
	theta = 360 / n;
	pinRadius = 0.5 * r;
    
    // The pins:
	for(i = [0 : n]){
		rotate(a = [0, 0, theta * i]){
			translate([inner, 0, 0]){
                sphere(r = r - 0.5*gap, center = true, $fn = 45);
                
            }
        }
    }
				
// The inner race:
	difference() {
		rad = inner - pinRadius - gap;
		cylinder(r1 = rad, r2 = rad, h = height, center = true, $fn = 45);
		rotate_extrude(convexity = 10){
			translate([inner, 0, 0]){
				circle(r = r + gap, $fn = 30);
            }
        }
        cylinder(d = hole, h = height + 5, center = true, $fn = 45);
	}
// The outer race:
	difference() {
		cylinder(r = outer, h = height, center = true, $fn = 45);
		rad = inner + pinRadius + gap;
			cylinder(r1 = rad, r2 = rad, h = height + 5, center = true, $fn = 45);
		rotate_extrude(convexity = 10)
			translate([inner, 0, 0])
				circle(r = r + gap, $fn = 45);
	}
}

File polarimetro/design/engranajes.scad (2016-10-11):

include <gears.scad>


dPol = 25.4/2;  //Media pulgada de polarizador
dEje = 16;
m = 2;
zG = 35;
zC = 20;

rG = m * zG / ( 2* PI);
rC = m * zC / (2 * PI);


$fn = 500;
module engranajes(){
//Eje


    translate([0,0,-15]){
    union(){
         difference(){
            union(){
                
                //Engranaje
                translate([0,0,10]){
                    gear(mm_per_tooth = m, number_of_teeth = zG, thickness = 10);
                }
                //Eje adosado al engranaje
                cylinder(d = dEje , h = 10, center = true);
                
                
            }
            //Agujero del eje
            cylinder(d = dPol + 0.5 , h = 50, center = true);
                 
        }
        
        
        //Stop de engranaje. Impide que se salga de lugar hacía adelante
        translate([0,0,4.5]){
            difference(){
                cylinder(r=rG+2, h = 1.5, center=true);
                cylinder(d = dEje , h = 1.5, center = true);
            }
        }
        
        //Apoyo de la lámina
        difference(){
                cylinder(d = dPol + 0.5 , h = 2, center = true);
                cylinder(d = dPol - 1 , h = 2, center = true);
        }
    }
}



    //Engranaje motor
    
        translate([rC+rG ,0,-5]){
            rotate([0,0, m * zG*180/PI]){
                difference(){
                    gear(mm_per_tooth = m, number_of_teeth = zC, thickness = 10);
                    cylinder(d=4,h=20,$fn=50,center=true);
                }
            
            }
        }
}

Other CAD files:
perfilador/mecanica/nema8/tambor.stl
polarimetro/design/soporte_polarimetro.dxf
perfilador/mecanica/nema17/soporte/soporte.sldprt
perfilador/mecanica/nema17/tambor/tambor.sldprt
polarimetro/design/gears.scad
perfilador/mecanica/nema17/encastre/soporte_base_50_5.STL
perfilador/mecanica/nema17/encastre/soporte_base_poste.STL
perfilador/mecanica/nema17/encastre/soporte_ph.STL
perfilador/mecanica/nema17/soporte/soporte_base.sldprt
perfilador/mecanica/nema17/soporte/soporte_perros.stl
perfilador/mecanica/nema17/soporte/soporte_v2.stl
perfilador/mecanica/nema17/soporte/soporte_v3_solido.sldprt
perfilador/mecanica/nema17/soporte/soporte_v4_solido.sldprt
perfilador/mecanica/nema17/soporte/soporte_v4_solido.stl
perfilador/mecanica/nema17/soporte/soporte_v5_solido.sldprt
perfilador/mecanica/nema17/soporte/soporte_v5_solido.stl
perfilador/mecanica/nema17/tambor/media_cania.stl
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

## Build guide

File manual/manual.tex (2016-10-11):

\documentclass[12pt,a4paper]{article}
\usepackage[spanish]{babel}
\usepackage[utf8]{inputenc}
\usepackage{graphicx}
\usepackage[font=footnotesize,labelfont=bf]{caption}
\usepackage[hmargin=1cm,vmargin=2cm]{geometry}
\usepackage{amsmath}
\usepackage{authblk}
\usepackage{url}
\usepackage{float}
\usepackage{multicol}
\usepackage{caption}
\usepackage{sectsty}
\usepackage{fancyhdr}
\usepackage{booktabs} %Agrego líneas a las tablas

\renewcommand{\baselinestretch}{1.5}
\renewcommand\spanishtablename{Tabla}

%Estilo
\sectionfont{\large}
%\pagestyle{fancy}
\renewcommand{\headrulewidth}{0pt}
\newcommand{\comment}[1]{} %Para hacer comentarios

\begin{document}

{\scshape\Huge Perfilador de haz \par}

{\Large Proyecto SOMA \par}

%\includegraphics[width=0.5\textwidth]{fig/logo}

\section{Especificaciones}

\begin{table}[H]
  \centering
  \begin{tabular}{|c|c|}
    \hline
    Diametro máximo de haz &  8 mm \\ \hline
    Diametro mínimo de haz &  0,5 mm\\ \hline
    Altura del eje óptico   &  5 cm\\ \hline
    Distancia del soporte al eje óptico &  3 cm\\ \hline
  \end{tabular}
  \caption{Especificaciones del haz y dimensiones mínimas}
  \label{tab:perfilador_mecanica}
\end{table}

\begin{table}[H]
  \centering
  \begin{tabular}{|c|c|}
    \hline
    Setup &  Observaciones \\ \hline
    Riel Thorlabs & \footnotesize En eje horizontal se necesita un poste \\ \hline
    Cage Thorlabs mayor a 30mm &   \\ \hline
  \end{tabular}
  \caption{Setups testeados}
  \label{tab:perfilador_setup}
\end{table}

\begin{table}[H]
  \centering
  \begin{tabular}{|c|c|}
    \hline
    Velocidad del motor &  20 rps \\ \hline
    Torque del motor    &  1.4Ncm \\ \hline
  \end{tabular}
  \caption{Detalles del motor y adquisición}
  \label{tab:electronica_adq}
\end{table}

\section{Electrónica}

\begin{table}[H]
  \centering
  \begin{tabular}{|c|c|}
    \hline
    Fuente &  $V > 8\text{V}$, $I>0,5\text{A}$ \\ \hline
    Conector alimentación &  Coaxial 5.5 mm \\ \hline
  \end{tabular}
  \caption{Especificaciones de la fuente de alimentación}
  \label{tab:electronica_tcp}
\end{table}

\begin{table}[H]
  \centering
  \begin{tabular}{|c|c|}
    \hline
    SSID &  WiFi-LEC \\ \hline
    IP (por defecto) &  192.168.0.100 \\ \hline
    Puerto TCP & 23 (Telnet) \\ \hline
    Tiempo de transmisión & 0,5s \\ \hline
  \end{tabular}
  \caption{Específicaciones de conexión}
  \label{tab:electronica_tcp}
\end{table}

En caso de que se haya alterado la IP
\begin{enumerate}
  \item Conectar PC al microcontrolador
  \item Abrir puerto serie creado.
  \item Imprimirá la IP una vez cada 10 s.
\end{enumerate}

\noindent Formato de salida (usar \texttt{telnet} IP\_SENSOR):

\begin{verbatim}
  1;1212
  2;1214
  ...
  Paso_i;Voltaje_i
  ...
  4000;1242
  END
\end{verbatim}

Tiempo de transmisión $\tau \approx 0,5\text{s}$

Preferiblemente usar GUI para obtener ajustes. Ingresar IP del sensor para usarla

\clearpage

\begin{figure}[H]
  \centering
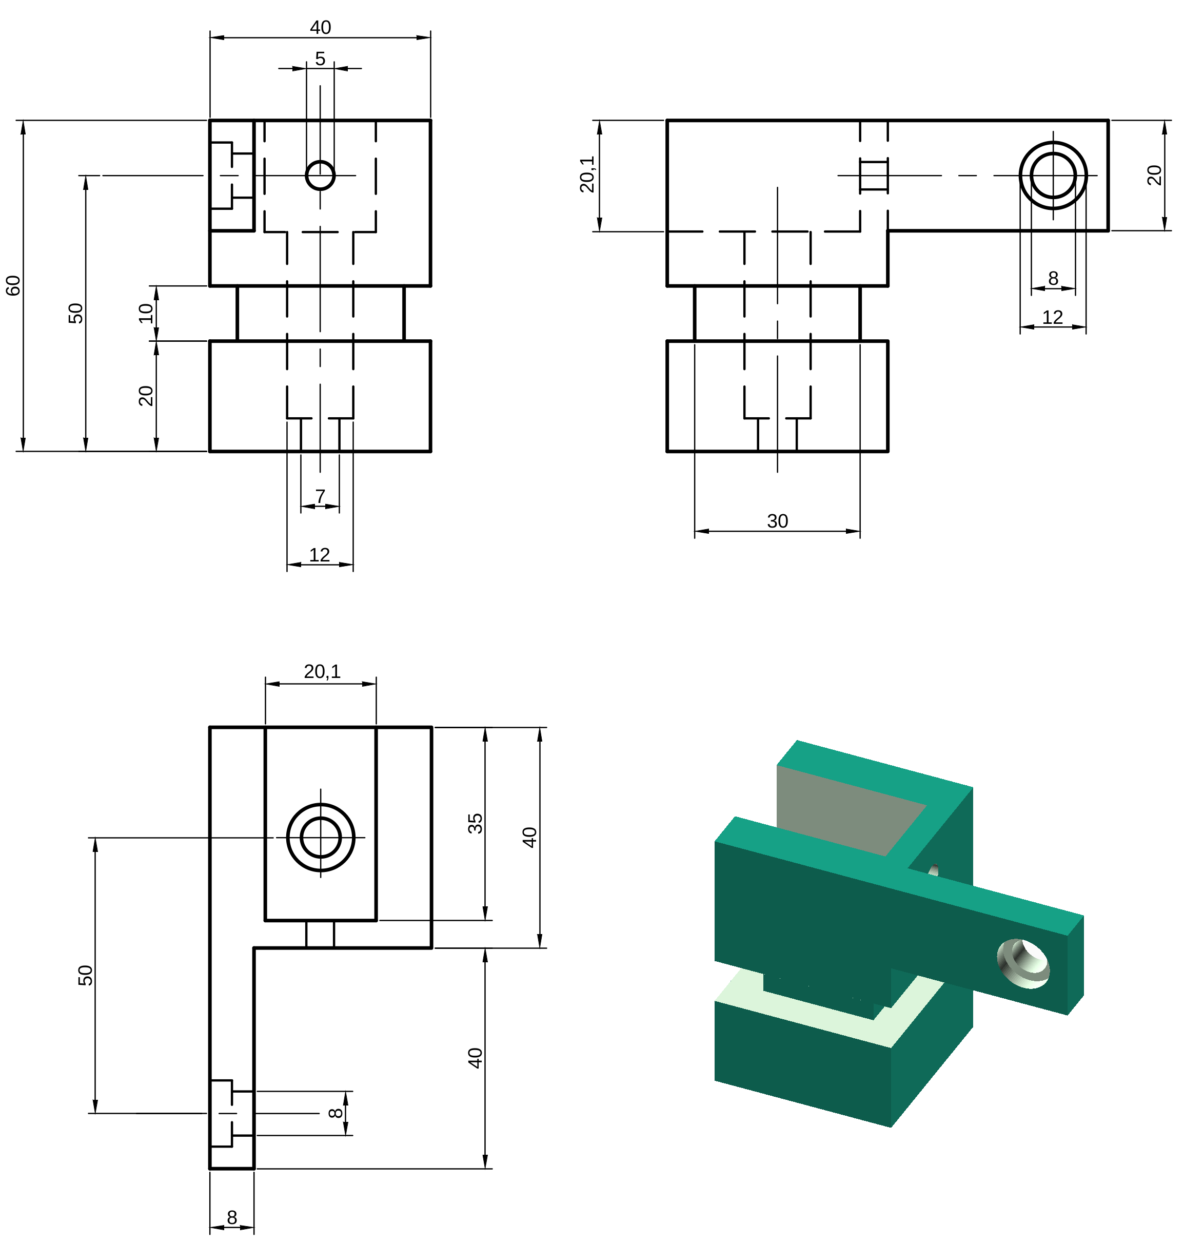
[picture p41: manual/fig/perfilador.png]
  
  \caption{Esquema mecánico del perfilador}
  \label{fig:perfilador}
\end{figure}

\begin{figure}[H]
  \centering
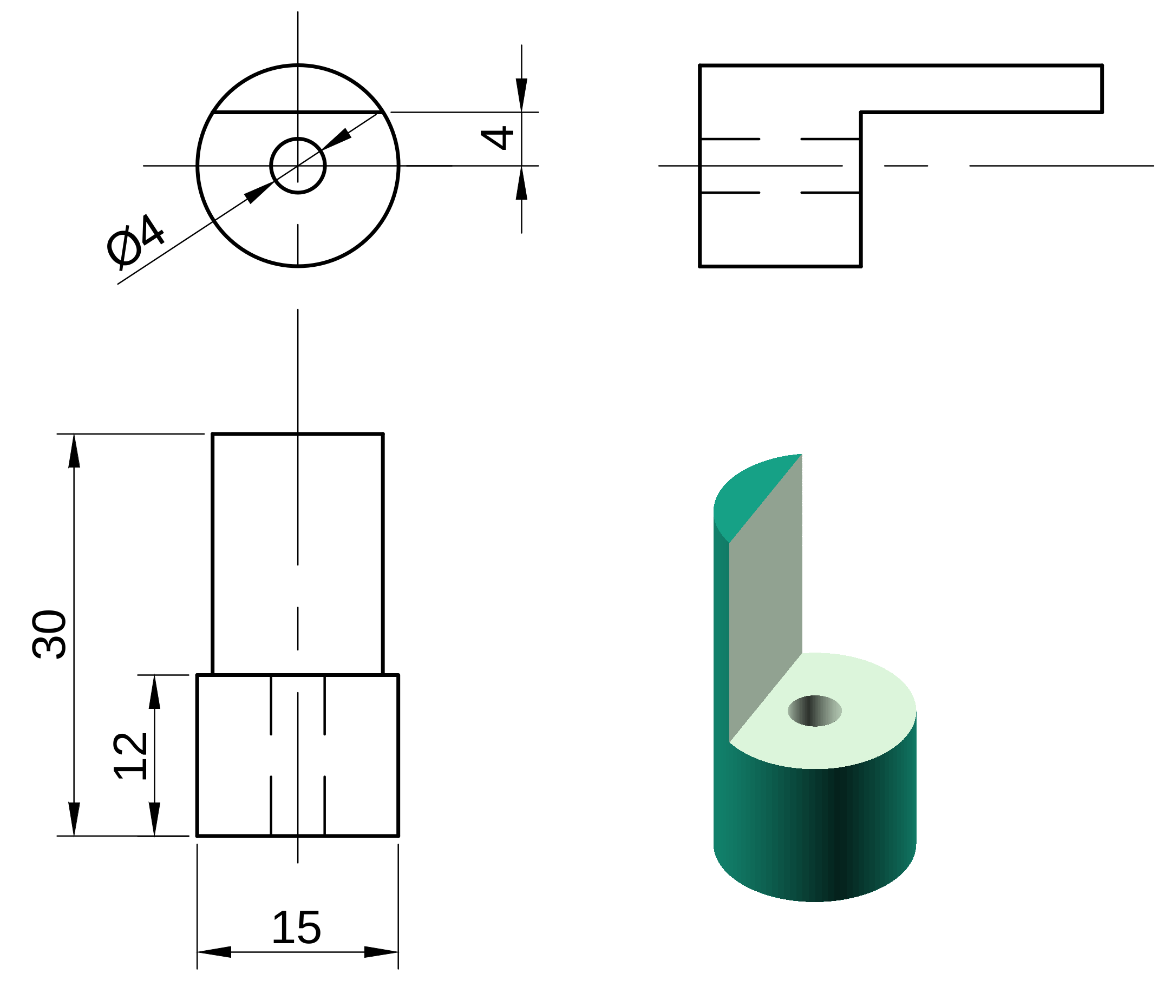
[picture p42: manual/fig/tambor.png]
  
  \caption{Esquema mecánico del tambor}
  \label{fig:perfilador}
\end{figure}

\clearpage

\begin{figure}[H]
  \centering
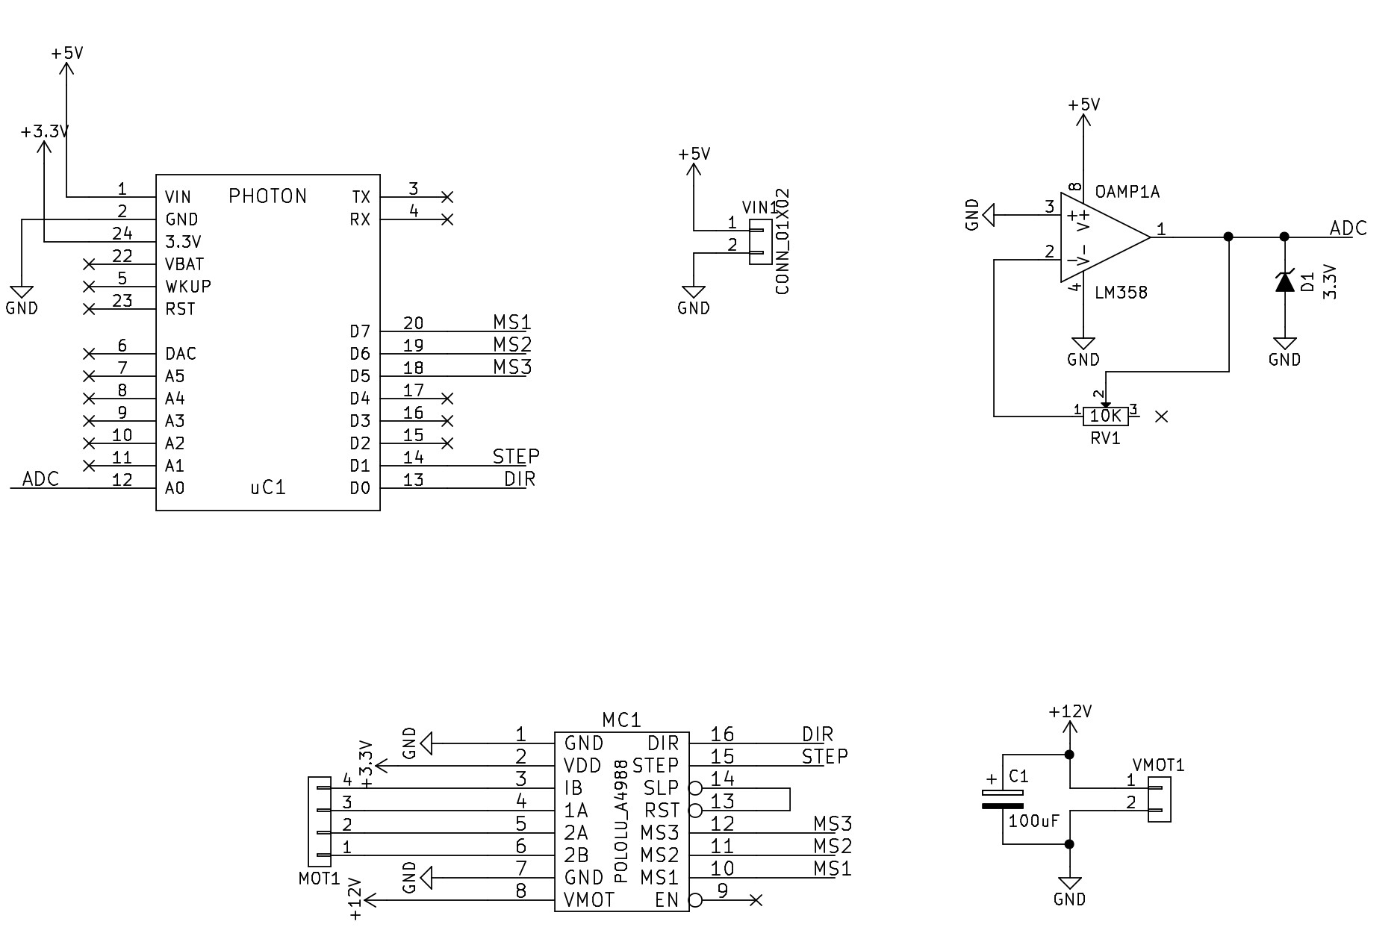
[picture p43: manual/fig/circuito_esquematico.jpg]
  
  \caption{Esquematico del circuito eléctronico del perfilador.}
  \label{fig:circuito_esquematico}
\end{figure}

\begin{figure}[H]
  \centering
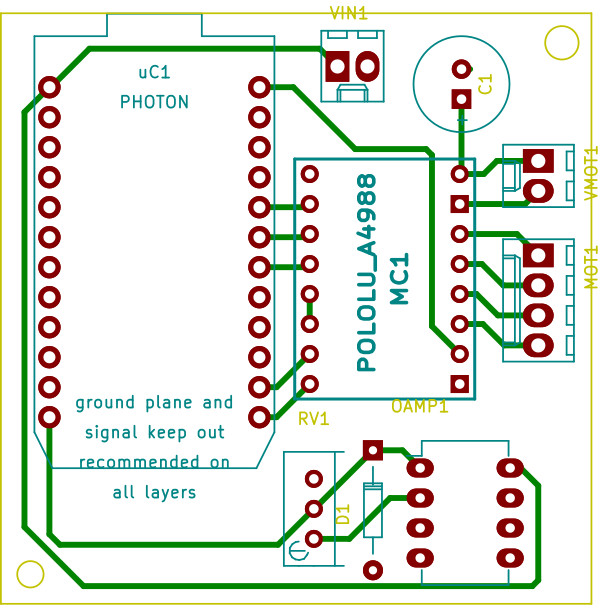
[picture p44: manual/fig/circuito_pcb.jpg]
  
  \caption{Plano del circuito impreso del perfilador}
  \label{fig:circuito_pcb}
\end{figure}

\end{document}

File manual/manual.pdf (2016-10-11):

### Perfilador de haz

## Proyecto SOMA

### 1. Especificaciones

Diametro m´aximo de haz | 8 mm
Diametro m´ınimo de haz | 0,5 mm
Altura del eje ´optico | 5 cm
Distancia del soporte al eje ´optico | 3 cm

Tabla 1: Especificaciones del haz y dimensiones m´ınimas

Setup | Observaciones
Riel Thorlabs | En eje horizontal se necesita un poste

Cage Thorlabs mayor a 30mm

Tabla 2: Setups testeados

Velocidad del motor | 20 rps
Torque del motor | 1.4Ncm

Tabla 3: Detalles del motor y adquisici´on

### 2. Electr´onica

Fuente | V > 8V, I > 0, 5A
Conector alimentaci´on | Coaxial 5.5 mm

Tabla 4: Especificaciones de la fuente de alimentaci´on

SSID | WiFi-LEC
IP | 192.168.0.100
Puerto TCP | 23 (Telnet)

Tabla 5: Configuraci´on de WiFi

En caso de que se haya alterado la IP

1. Conectar PC al microcontrolador
2. Abrir puerto serie creado.
3. Imprimir´a la IP una vez cada 10 s.

Formato de salida (usar telnet IP SENSOR):

1;1212

2;1214

Paso_i;Voltaje_i

4000;1242

END

Tiempo de transmisi´on τ ≈ 0, 5s

Preferiblemente usar GUI para obtener ajustes. Ingresar IP del sensor para usarla

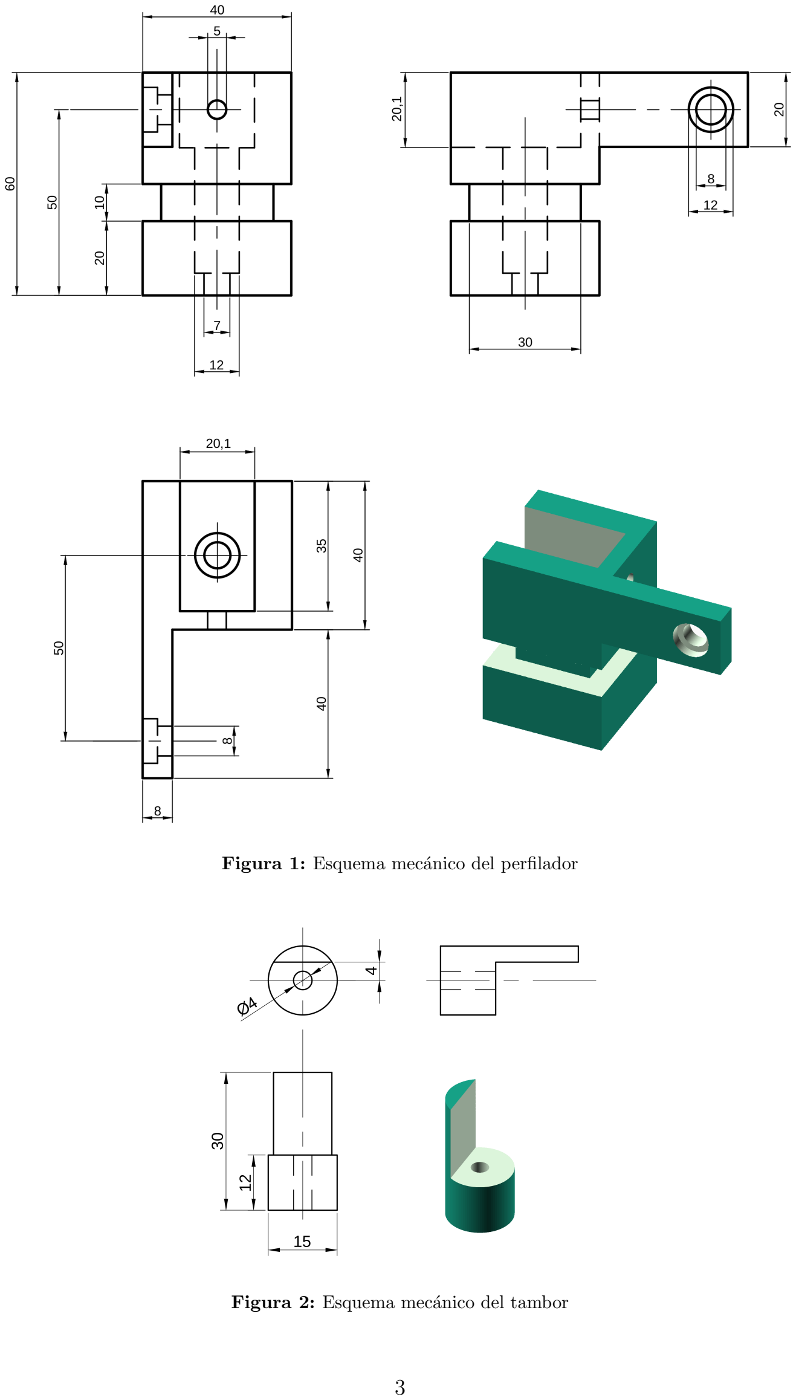
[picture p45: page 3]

Figura 1: Esquema mec´anico del perfilador

Figura 2: Esquema mec´anico del tambor

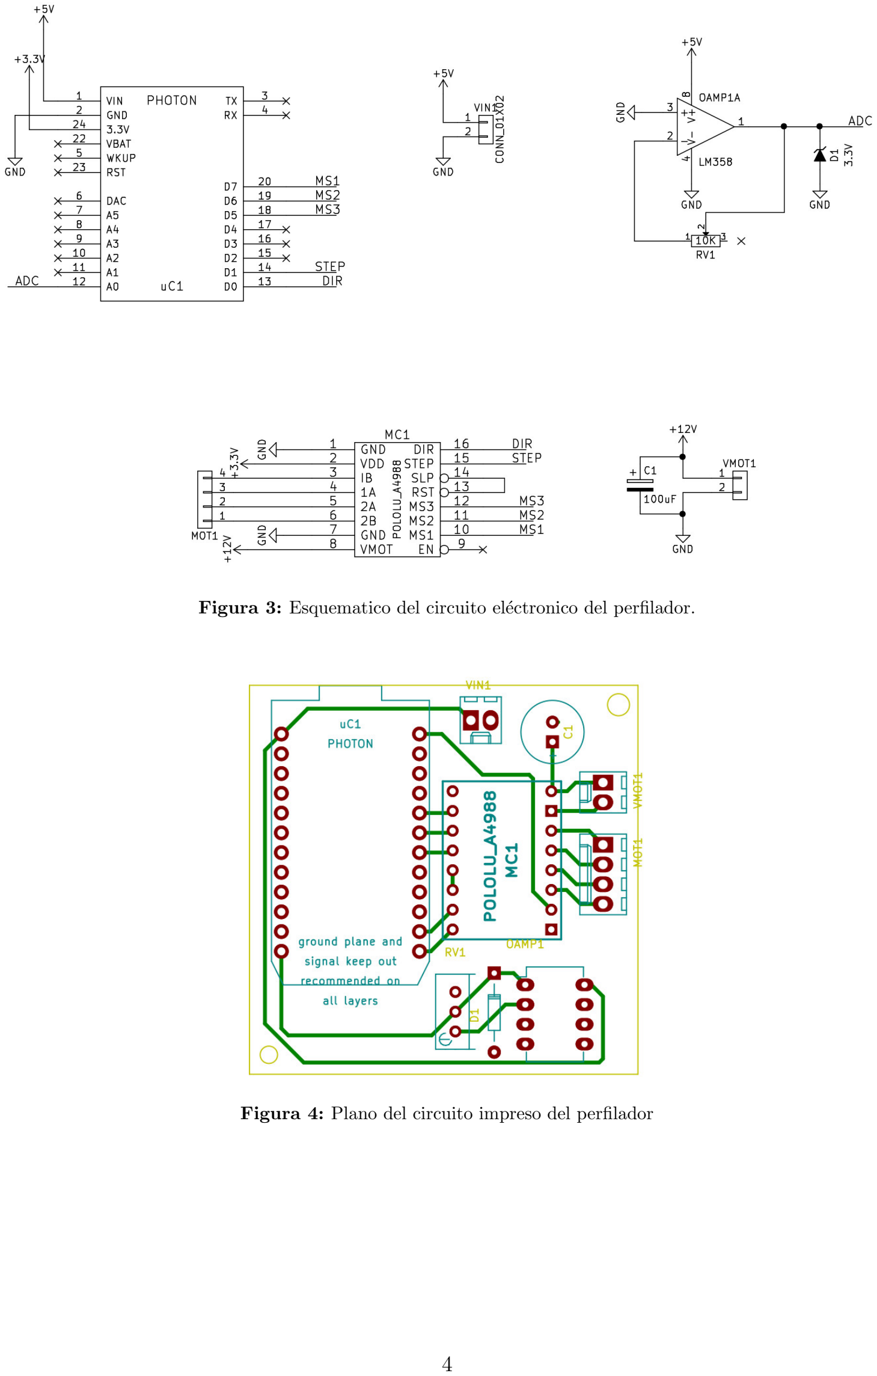
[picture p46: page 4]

Figura 3: Esquematico del circuito el´ectronico del perfilador.

Figura 4: Plano del circuito impreso del perfilador

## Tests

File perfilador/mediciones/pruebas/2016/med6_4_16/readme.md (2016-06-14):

Estas mediciones se hicieron con el motor sostenido por perros para impedir el movimiento del motor. Se observa que no está la diferencia que se encuentra en las mediciones hechas el 1/4/2016. También se usó la fuente de corriente, con una sensibilidad de 1uA/V y un filtro pasabajos de 12dB con corte en 1kHz. A misma frecuencia de rotación se midió en ambas direcciones. También se midió en ambos extremos del tambor

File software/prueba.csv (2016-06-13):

5.590970970000000000e+08 | 1.800000000000000000e+01
5.590972880000000000e+08 | 1.700000000000000000e+01
5.590974790000000000e+08 | 1.700000000000000000e+01
5.590976710000000000e+08 | 1.400000000000000000e+01
5.590978620000000000e+08 | 1.400000000000000000e+01
5.590980590000000000e+08 | 1.900000000000000000e+01
5.590982500000000000e+08 | 1.900000000000000000e+01
5.590984420000000000e+08 | 1.600000000000000000e+01
5.590986330000000000e+08 | 1.700000000000000000e+01
5.590988240000000000e+08 | 1.800000000000000000e+01
5.590990160000000000e+08 | 1.400000000000000000e+01
5.590992070000000000e+08 | 1.700000000000000000e+01
5.590993980000000000e+08 | 1.100000000000000000e+01
5.590995900000000000e+08 | 2.100000000000000000e+01
5.590997810000000000e+08 | 1.600000000000000000e+01
5.590999720000000000e+08 | 2.200000000000000000e+01
5.591001640000000000e+08 | 1.500000000000000000e+01
5.591003550000000000e+08 | 1.800000000000000000e+01
5.591005460000000000e+08 | 2.100000000000000000e+01
5.591008330000000000e+08 | 1.400000000000000000e+01
5.591011760000000000e+08 | 1.800000000000000000e+01
5.591013670000000000e+08 | 1.700000000000000000e+01
5.591015610000000000e+08 | 1.900000000000000000e+01
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

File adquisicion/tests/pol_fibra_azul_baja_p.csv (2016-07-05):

0.000000000000000000e+00 | 9.980000000000000000e+02
1.000000000000000000e+00 | 3.070000000000000000e+02
2.000000000000000000e+00 | 1.910000000000000000e+02
3.000000000000000000e+00 | 6.850000000000000000e+02
4.000000000000000000e+00 | 7.500000000000000000e+02
5.000000000000000000e+00 | 6.100000000000000000e+01
6.000000000000000000e+00 | 7.000000000000000000e+02
7.000000000000000000e+00 | 1.095000000000000000e+03
8.000000000000000000e+00 | 1.242000000000000000e+03
9.000000000000000000e+00 | 1.245000000000000000e+03
1.000000000000000000e+01 | 1.771000000000000000e+03
1.100000000000000000e+01 | 9.570000000000000000e+02
1.200000000000000000e+01 | 1.730000000000000000e+02
1.300000000000000000e+01 | 2.372000000000000000e+03
1.400000000000000000e+01 | 8.590000000000000000e+02
1.500000000000000000e+01 | 5.900000000000000000e+01
1.600000000000000000e+01 | 5.900000000000000000e+01
1.700000000000000000e+01 | 6.230000000000000000e+02
1.800000000000000000e+01 | 1.602000000000000000e+03
1.900000000000000000e+01 | 1.867000000000000000e+03
2.000000000000000000e+01 | 1.320000000000000000e+02
2.100000000000000000e+01 | 5.730000000000000000e+02
2.200000000000000000e+01 | 2.530000000000000000e+02
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

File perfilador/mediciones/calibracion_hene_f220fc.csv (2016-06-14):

#um uW
0 330
50 310
100 320
150 260
175 220
200 170
225 100
250 50
275 20
300 12.1
325 5.5
350 2.8
375 1.2
400 0.5
425 0.2

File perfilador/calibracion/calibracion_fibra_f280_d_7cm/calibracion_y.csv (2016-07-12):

#d[um] | V[V] | DeltaV
0 | 260 | 30
200 | 260 | 30
400 | 260 | 30
600 | 260 | 30
800 | 260 | 30
1000 | 260 | 30
1200 | 250 | 30
1400 | 250 | 30
1600 | 220 | 30
1800 | 200 | 30
2000 | 180 | 30
2100 | 170 | 30
2200 | 160 | 30
2300 | 150 | 30
2400 | 140 | 30
2500 | 120 | 30
2600 | 100 | 30
2700 | 90 | 10
2800 | 85 | 10
2900 | 75 | 10
3000 | 65 | 10
3100 | 55 | 10
3200 | 45 | 10
3300 | 35 | 10
3400 | 30 | 10
3500 | 25 | 2
3600 | 22 | 2
3700 | 18 | 2
3800 | 16 | 2
3900 | 13 | 2
4000 | 10 | 1
4100 | 8 | 1
4200 | 7 | 1
4300 | 6 | 1
4400 | 5 | 1
4500 | 4 | 1
4600 | 3 | 1
4700 | 2.5 | 0.5
4800 | 1.9 | 0.5
4900 | 1.5 | 0.2
5000 | 1.2 | 0.2
5100 | 1 | 0.1
5200 | 0.8 | 0.1
5300 | 0.7 | 0.1
5400 | 0.6 | 0.1

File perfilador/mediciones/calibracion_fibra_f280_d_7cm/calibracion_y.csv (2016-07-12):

#d[um] | V[V] | DeltaV
0 | 270 | 30
200 | 270 | 30
400 | 270 | 30
600 | 270 | 30
800 | 270 | 30
1000 | 260 | 30
1200 | 250 | 30
1400 | 240 | 30
1600 | 230 | 30
1800 | 220 | 30
2000 | 190 | 30
2100 | 180 | 30
2200 | 170 | 30
2300 | 160 | 30
2400 | 150 | 30
2500 | 140 | 30
2600 | 120 | 30
2700 | 95 | 10
2800 | 90 | 10
2900 | 75 | 10
3000 | 65 | 10
3100 | 55 | 10
3200 | 45 | 10
3300 | 35 | 10
3400 | 30 | 10
3500 | 22 | 2
3600 | 20 | 2
3700 | 16 | 2
3800 | 17 | 2
3900 | 11 | 2
4000 | 9 | 1
4100 | 8 | 1
4200 | 6 | 1
4300 | 5 | 1
4400 | 4 | 1
4500 | 3 | 1
4600 | 2 | 1
4700 | 2.0 | 0.5
4800 | 1.8 | 0.5
4900 | 1.4 | 0.2
5000 | 1.3 | 0.2
5100 | 1.1 | 0.1
5200 | 0.6 | 0.1
5300 | 0.4 | 0.1
5400 | 0.3 | 0.1

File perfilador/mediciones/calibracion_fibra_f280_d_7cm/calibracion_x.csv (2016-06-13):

#d[um] | A[uW] | errA[uW]
0 | 270 | 20
200 | 270 | 20
500 | 270 | 20
750 | 280 | 20
1000 | 270 | 20
1250 | 250 | 10
1500 | 240 | 10
1750 | 240 | 10
2000 | 220 | 10
2250 | 220 | 10
2500 | 200 | 10
2600 | 190 | 10
2700 | 180 | 10
2800 | 170 | 10
2900 | 160 | 10
3000 | 150 | 10
3100 | 135 | 10
3200 | 120 | 10
3300 | 115 | 10
3400 | 100 | 10
3500 | 90 | 5
3600 | 75 | 5
3700 | 65 | 5
3800 | 55 | 5
3900 | 45 | 5
4000 | 35 | 5
4100 | 30 | 5
4200 | 25 | 5
4300 | 20 | 5
4400 | 15 | 5
4500 | 10 | 5
4600 | 9 | 1
4700 | 8.5 | 0.5
4800 | 6.5 | 0.5
4900 | 5.5 | 0.5
5000 | 4.5 | 0.5
5100 | 3.5 | 0.5
5200 | 2.5 | 0.5
5300 | 2.0 | 0.5
5400 | 1.5 | 0.5
5500 | 1.2 | 0.2
5600 | 1.0 | 0.1
5700 | 0.7 | 0.1
4200 | 25 | 5

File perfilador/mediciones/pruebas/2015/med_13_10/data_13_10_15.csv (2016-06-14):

4.320000000000000000e+02 0.000000000000000000e+00
1.573520000000000000e+06 4.730000000000000000e+02
1.573913000000000000e+06 4.750000000000000000e+02
1.574306000000000000e+06 4.780000000000000000e+02
1.574698000000000000e+06 4.780000000000000000e+02
1.575092000000000000e+06 4.730000000000000000e+02
1.575484000000000000e+06 4.750000000000000000e+02
1.575876000000000000e+06 4.780000000000000000e+02
1.576270000000000000e+06 4.750000000000000000e+02
1.576662000000000000e+06 4.760000000000000000e+02
1.577056000000000000e+06 4.760000000000000000e+02
1.577448000000000000e+06 4.750000000000000000e+02
1.577840000000000000e+06 4.750000000000000000e+02
1.578234000000000000e+06 4.740000000000000000e+02
1.578626000000000000e+06 4.750000000000000000e+02
1.579020000000000000e+06 4.740000000000000000e+02
1.579412000000000000e+06 4.700000000000000000e+02
1.579804000000000000e+06 4.710000000000000000e+02
1.580198000000000000e+06 4.720000000000000000e+02
1.580590000000000000e+06 4.760000000000000000e+02
1.580982000000000000e+06 4.750000000000000000e+02
1.581376000000000000e+06 4.730000000000000000e+02
1.581768000000000000e+06 4.760000000000000000e+02
1.582162000000000000e+06 4.760000000000000000e+02
1.582554000000000000e+06 4.780000000000000000e+02
1.582946000000000000e+06 4.780000000000000000e+02
1.583340000000000000e+06 4.770000000000000000e+02
1.583732000000000000e+06 4.770000000000000000e+02
1.584125000000000000e+06 4.770000000000000000e+02
1.584518000000000000e+06 4.770000000000000000e+02
1.584910000000000000e+06 4.770000000000000000e+02
1.585304000000000000e+06 4.770000000000000000e+02
1.585696000000000000e+06 4.760000000000000000e+02
1.586089000000000000e+06 4.730000000000000000e+02
1.586482000000000000e+06 4.750000000000000000e+02
1.586874000000000000e+06 4.700000000000000000e+02
1.587268000000000000e+06 4.740000000000000000e+02
1.587660000000000000e+06 4.720000000000000000e+02
1.588053000000000000e+06 4.760000000000000000e+02
1.588446000000000000e+06 4.740000000000000000e+02
1.588838000000000000e+06 4.730000000000000000e+02
1.589231000000000000e+06 4.710000000000000000e+02
1.589624000000000000e+06 4.700000000000000000e+02
1.590017000000000000e+06 4.730000000000000000e+02
1.590410000000000000e+06 4.720000000000000000e+02
1.590802000000000000e+06 4.710000000000000000e+02
1.591195000000000000e+06 4.730000000000000000e+02
1.591588000000000000e+06 4.770000000000000000e+02
1.591980000000000000e+06 4.750000000000000000e+02
1.592373000000000000e+06 4.740000000000000000e+02
1.592766000000000000e+06 4.750000000000000000e+02
1.593159000000000000e+06 4.800000000000000000e+02
1.593552000000000000e+06 4.710000000000000000e+02
1.593944000000000000e+06 4.720000000000000000e+02
1.594337000000000000e+06 4.710000000000000000e+02
1.594730000000000000e+06 4.700000000000000000e+02
1.595123000000000000e+06 4.700000000000000000e+02
1.595515000000000000e+06 4.620000000000000000e+02
1.595908000000000000e+06 4.660000000000000000e+02
1.596301000000000000e+06 4.600000000000000000e+02
1.596694000000000000e+06 4.640000000000000000e+02
1.597087000000000000e+06 4.620000000000000000e+02
1.597479000000000000e+06 4.640000000000000000e+02
1.597872000000000000e+06 4.690000000000000000e+02
1.598265000000000000e+06 4.620000000000000000e+02
1.598657000000000000e+06 4.460000000000000000e+02
1.599051000000000000e+06 4.580000000000000000e+02
1.599443000000000000e+06 4.680000000000000000e+02
1.599836000000000000e+06 4.630000000000000000e+02
1.600229000000000000e+06 4.600000000000000000e+02
1.600621000000000000e+06 4.630000000000000000e+02
1.601015000000000000e+06 4.620000000000000000e+02
1.601407000000000000e+06 4.650000000000000000e+02
1.601799000000000000e+06 4.720000000000000000e+02
1.602193000000000000e+06 4.650000000000000000e+02
1.602585000000000000e+06 4.630000000000000000e+02
1.602978000000000000e+06 4.680000000000000000e+02
1.603371000000000000e+06 4.720000000000000000e+02
1.603763000000000000e+06 4.630000000000000000e+02
1.604157000000000000e+06 4.630000000000000000e+02
1.604549000000000000e+06 4.620000000000000000e+02
1.604942000000000000e+06 4.620000000000000000e+02
1.605335000000000000e+06 4.600000000000000000e+02
1.605727000000000000e+06 4.590000000000000000e+02
1.606121000000000000e+06 4.580000000000000000e+02
1.606513000000000000e+06 4.580000000000000000e+02
1.606905000000000000e+06 4.580000000000000000e+02
1.607299000000000000e+06 4.610000000000000000e+02
1.607691000000000000e+06 4.600000000000000000e+02
1.608085000000000000e+06 4.610000000000000000e+02
1.608477000000000000e+06 4.590000000000000000e+02
1.608869000000000000e+06 4.610000000000000000e+02
1.609263000000000000e+06 4.570000000000000000e+02
1.609655000000000000e+06 4.600000000000000000e+02
1.610048000000000000e+06 4.570000000000000000e+02
1.610441000000000000e+06 4.600000000000000000e+02
1.610833000000000000e+06 4.550000000000000000e+02
1.611227000000000000e+06 4.590000000000000000e+02
1.611619000000000000e+06 4.560000000000000000e+02
1.612012000000000000e+06 4.580000000000000000e+02
1.612405000000000000e+06 4.540000000000000000e+02
1.612797000000000000e+06 4.540000000000000000e+02
1.613190000000000000e+06 4.540000000000000000e+02
1.613583000000000000e+06 4.540000000000000000e+02
1.613975000000000000e+06 4.510000000000000000e+02
1.614369000000000000e+06 4.530000000000000000e+02
1.614761000000000000e+06 4.500000000000000000e+02
1.615154000000000000e+06 4.490000000000000000e+02
1.615547000000000000e+06 4.510000000000000000e+02
1.615939000000000000e+06 4.490000000000000000e+02
1.616333000000000000e+06 4.500000000000000000e+02
1.616725000000000000e+06 4.540000000000000000e+02
1.617118000000000000e+06 4.480000000000000000e+02
1.617511000000000000e+06 4.580000000000000000e+02
1.617903000000000000e+06 4.490000000000000000e+02
1.618296000000000000e+06 4.530000000000000000e+02
1.618689000000000000e+06 4.490000000000000000e+02
1.619082000000000000e+06 4.480000000000000000e+02
1.619475000000000000e+06 4.460000000000000000e+02
1.619867000000000000e+06 4.500000000000000000e+02
1.620260000000000000e+06 4.460000000000000000e+02
1.620653000000000000e+06 4.490000000000000000e+02
1.621046000000000000e+06 4.440000000000000000e+02
1.621438000000000000e+06 4.410000000000000000e+02
1.621831000000000000e+06 4.450000000000000000e+02
1.622224000000000000e+06 4.470000000000000000e+02
1.622617000000000000e+06 4.440000000000000000e+02
1.623010000000000000e+06 4.490000000000000000e+02
1.623402000000000000e+06 4.440000000000000000e+02
1.623795000000000000e+06 4.430000000000000000e+02
1.624188000000000000e+06 4.410000000000000000e+02
1.624580000000000000e+06 4.460000000000000000e+02
1.624973000000000000e+06 4.410000000000000000e+02
1.625366000000000000e+06 4.390000000000000000e+02
1.625759000000000000e+06 4.390000000000000000e+02
1.626152000000000000e+06 4.440000000000000000e+02
1.626544000000000000e+06 4.340000000000000000e+02
1.626937000000000000e+06 4.380000000000000000e+02
1.627330000000000000e+06 4.290000000000000000e+02
1.627722000000000000e+06 4.220000000000000000e+02
1.628116000000000000e+06 4.230000000000000000e+02
1.628508000000000000e+06 4.180000000000000000e+02
1.628901000000000000e+06 4.080000000000000000e+02
1.629294000000000000e+06 4.010000000000000000e+02
1.629686000000000000e+06 3.830000000000000000e+02
1.630080000000000000e+06 3.700000000000000000e+02
1.630472000000000000e+06 3.470000000000000000e+02
1.630864000000000000e+06 3.280000000000000000e+02
1.631258000000000000e+06 2.920000000000000000e+02
1.631650000000000000e+06 2.610000000000000000e+02
1.632044000000000000e+06 2.270000000000000000e+02
1.632436000000000000e+06 1.910000000000000000e+02
1.632828000000000000e+06 1.580000000000000000e+02
1.633222000000000000e+06 1.310000000000000000e+02
1.633614000000000000e+06 1.030000000000000000e+02
1.634008000000000000e+06 8.200000000000000000e+01
1.634400000000000000e+06 6.300000000000000000e+01
1.634792000000000000e+06 4.800000000000000000e+01
1.635186000000000000e+06 3.700000000000000000e+01
1.635578000000000000e+06 3.000000000000000000e+01
1.635970000000000000e+06 2.100000000000000000e+01
1.636364000000000000e+06 1.500000000000000000e+01
1.636756000000000000e+06 9.000000000000000000e+00
1.637150000000000000e+06 2.000000000000000000e+00
1.637542000000000000e+06 4.000000000000000000e+00
1.637934000000000000e+06 0.000000000000000000e+00
1.638328000000000000e+06 0.000000000000000000e+00
1.638720000000000000e+06 5.000000000000000000e+00
1.639113000000000000e+06 0.000000000000000000e+00
1.639506000000000000e+06 0.000000000000000000e+00
1.639898000000000000e+06 0.000000000000000000e+00
1.640292000000000000e+06 0.000000000000000000e+00
1.640684000000000000e+06 0.000000000000000000e+00
1.641077000000000000e+06 0.000000000000000000e+00
1.641470000000000000e+06 0.000000000000000000e+00
1.641862000000000000e+06 0.000000000000000000e+00
1.642256000000000000e+06 0.000000000000000000e+00
1.642648000000000000e+06 0.000000000000000000e+00
1.643041000000000000e+06 0.000000000000000000e+00
1.643434000000000000e+06 0.000000000000000000e+00
1.643826000000000000e+06 0.000000000000000000e+00
1.644219000000000000e+06 0.000000000000000000e+00
1.644612000000000000e+06 0.000000000000000000e+00
1.645005000000000000e+06 0.000000000000000000e+00
1.645398000000000000e+06 0.000000000000000000e+00
1.645790000000000000e+06 0.000000000000000000e+00
1.646183000000000000e+06 0.000000000000000000e+00
1.646576000000000000e+06 0.000000000000000000e+00
1.646968000000000000e+06 0.000000000000000000e+00
1.647361000000000000e+06 0.000000000000000000e+00
1.647754000000000000e+06 0.000000000000000000e+00
1.648147000000000000e+06 0.000000000000000000e+00
1.648540000000000000e+06 0.000000000000000000e+00
1.648932000000000000e+06 0.000000000000000000e+00
1.649325000000000000e+06 0.000000000000000000e+00
1.649718000000000000e+06 0.000000000000000000e+00
1.650111000000000000e+06 0.000000000000000000e+00
1.650503000000000000e+06 0.000000000000000000e+00
1.650896000000000000e+06 0.000000000000000000e+00
1.651289000000000000e+06 1.000000000000000000e+00
1.651682000000000000e+06 0.000000000000000000e+00
1.652075000000000000e+06 0.000000000000000000e+00
1.652467000000000000e+06 0.000000000000000000e+00
1.652860000000000000e+06 0.000000000000000000e+00
1.653253000000000000e+06 0.000000000000000000e+00
1.653645000000000000e+06 0.000000000000000000e+00
1.654039000000000000e+06 0.000000000000000000e+00
1.654431000000000000e+06 0.000000000000000000e+00
1.654824000000000000e+06 0.000000000000000000e+00
1.655217000000000000e+06 0.000000000000000000e+00
1.655609000000000000e+06 0.000000000000000000e+00
1.656003000000000000e+06 0.000000000000000000e+00
1.656395000000000000e+06 0.000000000000000000e+00
1.656787000000000000e+06 0.000000000000000000e+00
1.657181000000000000e+06 0.000000000000000000e+00
1.657573000000000000e+06 0.000000000000000000e+00
1.657966000000000000e+06 0.000000000000000000e+00
1.658359000000000000e+06 0.000000000000000000e+00
1.658751000000000000e+06 0.000000000000000000e+00
1.659145000000000000e+06 0.000000000000000000e+00
1.659537000000000000e+06 0.000000000000000000e+00
1.659930000000000000e+06 0.000000000000000000e+00
1.660323000000000000e+06 0.000000000000000000e+00
1.660715000000000000e+06 0.000000000000000000e+00
1.661109000000000000e+06 0.000000000000000000e+00
1.661501000000000000e+06 0.000000000000000000e+00
1.661893000000000000e+06 0.000000000000000000e+00
1.662287000000000000e+06 0.000000000000000000e+00
1.662679000000000000e+06 0.000000000000000000e+00
1.663073000000000000e+06 0.000000000000000000e+00
1.663465000000000000e+06 0.000000000000000000e+00
1.663857000000000000e+06 0.000000000000000000e+00
1.664251000000000000e+06 0.000000000000000000e+00
1.664643000000000000e+06 0.000000000000000000e+00
1.665036000000000000e+06 0.000000000000000000e+00
1.665429000000000000e+06 0.000000000000000000e+00
1.665821000000000000e+06 0.000000000000000000e+00
1.666215000000000000e+06 0.000000000000000000e+00
1.666607000000000000e+06 0.000000000000000000e+00
1.667000000000000000e+06 0.000000000000000000e+00
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

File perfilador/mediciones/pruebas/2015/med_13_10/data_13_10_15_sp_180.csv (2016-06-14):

3.200000000000000000e+01 0.000000000000000000e+00
1.492791000000000000e+06 1.900000000000000000e+01
1.493165000000000000e+06 1.200000000000000000e+01
1.493537000000000000e+06 7.000000000000000000e+00
1.493909000000000000e+06 3.000000000000000000e+00
1.494283000000000000e+06 2.000000000000000000e+00
1.494655000000000000e+06 0.000000000000000000e+00
1.495028000000000000e+06 0.000000000000000000e+00
1.495401000000000000e+06 0.000000000000000000e+00
1.495773000000000000e+06 0.000000000000000000e+00
1.496146000000000000e+06 0.000000000000000000e+00
1.496519000000000000e+06 0.000000000000000000e+00
1.496891000000000000e+06 0.000000000000000000e+00
1.497264000000000000e+06 0.000000000000000000e+00
1.497636000000000000e+06 0.000000000000000000e+00
1.498010000000000000e+06 0.000000000000000000e+00
1.498382000000000000e+06 0.000000000000000000e+00
1.498754000000000000e+06 0.000000000000000000e+00
1.499128000000000000e+06 0.000000000000000000e+00
1.499500000000000000e+06 0.000000000000000000e+00
1.499872000000000000e+06 0.000000000000000000e+00
1.500246000000000000e+06 0.000000000000000000e+00
1.500618000000000000e+06 0.000000000000000000e+00
1.500990000000000000e+06 0.000000000000000000e+00
1.501364000000000000e+06 0.000000000000000000e+00
1.501736000000000000e+06 0.000000000000000000e+00
1.502109000000000000e+06 0.000000000000000000e+00
1.502482000000000000e+06 0.000000000000000000e+00
1.502854000000000000e+06 0.000000000000000000e+00
1.503227000000000000e+06 0.000000000000000000e+00
1.503600000000000000e+06 0.000000000000000000e+00
1.503972000000000000e+06 0.000000000000000000e+00
1.504345000000000000e+06 0.000000000000000000e+00
1.504717000000000000e+06 0.000000000000000000e+00
1.505091000000000000e+06 0.000000000000000000e+00
1.505463000000000000e+06 0.000000000000000000e+00
1.505835000000000000e+06 0.000000000000000000e+00
1.506209000000000000e+06 0.000000000000000000e+00
1.506581000000000000e+06 0.000000000000000000e+00
1.506953000000000000e+06 0.000000000000000000e+00
1.507327000000000000e+06 0.000000000000000000e+00
1.507699000000000000e+06 0.000000000000000000e+00
1.508072000000000000e+06 0.000000000000000000e+00
1.508445000000000000e+06 0.000000000000000000e+00
1.508817000000000000e+06 0.000000000000000000e+00
1.509190000000000000e+06 0.000000000000000000e+00
1.509563000000000000e+06 0.000000000000000000e+00
1.509935000000000000e+06 0.000000000000000000e+00
1.510308000000000000e+06 0.000000000000000000e+00
1.510680000000000000e+06 0.000000000000000000e+00
1.511054000000000000e+06 0.000000000000000000e+00
1.511426000000000000e+06 0.000000000000000000e+00
1.511798000000000000e+06 0.000000000000000000e+00
1.512172000000000000e+06 0.000000000000000000e+00
1.512544000000000000e+06 0.000000000000000000e+00
1.512916000000000000e+06 0.000000000000000000e+00
1.513290000000000000e+06 0.000000000000000000e+00
1.513662000000000000e+06 0.000000000000000000e+00
1.514035000000000000e+06 0.000000000000000000e+00
1.514408000000000000e+06 0.000000000000000000e+00
1.514780000000000000e+06 0.000000000000000000e+00
1.515153000000000000e+06 0.000000000000000000e+00
1.515526000000000000e+06 0.000000000000000000e+00
1.515898000000000000e+06 0.000000000000000000e+00
1.516271000000000000e+06 0.000000000000000000e+00
1.516644000000000000e+06 0.000000000000000000e+00
1.517017000000000000e+06 0.000000000000000000e+00
1.517389000000000000e+06 0.000000000000000000e+00
1.517761000000000000e+06 0.000000000000000000e+00
1.518135000000000000e+06 0.000000000000000000e+00
1.518507000000000000e+06 0.000000000000000000e+00
1.518879000000000000e+06 0.000000000000000000e+00
1.519253000000000000e+06 0.000000000000000000e+00
1.519625000000000000e+06 0.000000000000000000e+00
1.519999000000000000e+06 0.000000000000000000e+00
1.520371000000000000e+06 0.000000000000000000e+00
1.520744000000000000e+06 0.000000000000000000e+00
1.521117000000000000e+06 0.000000000000000000e+00
1.521489000000000000e+06 0.000000000000000000e+00
1.521862000000000000e+06 0.000000000000000000e+00
1.522235000000000000e+06 0.000000000000000000e+00
1.522607000000000000e+06 0.000000000000000000e+00
1.522979000000000000e+06 0.000000000000000000e+00
1.523353000000000000e+06 0.000000000000000000e+00
1.523725000000000000e+06 0.000000000000000000e+00
1.524098000000000000e+06 0.000000000000000000e+00
1.524471000000000000e+06 0.000000000000000000e+00
1.524843000000000000e+06 0.000000000000000000e+00
1.525216000000000000e+06 0.000000000000000000e+00
1.525589000000000000e+06 0.000000000000000000e+00
1.525961000000000000e+06 0.000000000000000000e+00
1.526334000000000000e+06 0.000000000000000000e+00
1.526707000000000000e+06 0.000000000000000000e+00
1.527080000000000000e+06 0.000000000000000000e+00
1.527452000000000000e+06 0.000000000000000000e+00
1.527825000000000000e+06 0.000000000000000000e+00
1.528198000000000000e+06 0.000000000000000000e+00
1.528570000000000000e+06 0.000000000000000000e+00
1.528942000000000000e+06 0.000000000000000000e+00
1.529316000000000000e+06 0.000000000000000000e+00
1.529688000000000000e+06 0.000000000000000000e+00
1.530061000000000000e+06 0.000000000000000000e+00
1.530434000000000000e+06 0.000000000000000000e+00
1.530806000000000000e+06 0.000000000000000000e+00
1.531179000000000000e+06 0.000000000000000000e+00
1.531552000000000000e+06 0.000000000000000000e+00
1.531924000000000000e+06 0.000000000000000000e+00
1.532297000000000000e+06 0.000000000000000000e+00
1.532670000000000000e+06 0.000000000000000000e+00
1.533043000000000000e+06 0.000000000000000000e+00
1.533415000000000000e+06 0.000000000000000000e+00
1.533788000000000000e+06 0.000000000000000000e+00
1.534161000000000000e+06 0.000000000000000000e+00
1.534533000000000000e+06 0.000000000000000000e+00
1.534906000000000000e+06 0.000000000000000000e+00
1.535279000000000000e+06 0.000000000000000000e+00
1.535651000000000000e+06 0.000000000000000000e+00
1.536025000000000000e+06 0.000000000000000000e+00
1.536397000000000000e+06 0.000000000000000000e+00
1.536769000000000000e+06 0.000000000000000000e+00
1.537143000000000000e+06 0.000000000000000000e+00
1.537515000000000000e+06 0.000000000000000000e+00
1.537887000000000000e+06 0.000000000000000000e+00
1.538260000000000000e+06 0.000000000000000000e+00
1.538633000000000000e+06 3.000000000000000000e+00
1.539006000000000000e+06 8.000000000000000000e+00
1.539378000000000000e+06 1.600000000000000000e+01
1.539751000000000000e+06 2.600000000000000000e+01
1.540124000000000000e+06 3.900000000000000000e+01
1.540496000000000000e+06 5.700000000000000000e+01
1.540869000000000000e+06 8.100000000000000000e+01
1.541242000000000000e+06 1.120000000000000000e+02
1.541614000000000000e+06 1.490000000000000000e+02
1.541987000000000000e+06 1.910000000000000000e+02
1.542360000000000000e+06 2.340000000000000000e+02
1.542732000000000000e+06 2.740000000000000000e+02
1.543106000000000000e+06 3.040000000000000000e+02
1.543478000000000000e+06 3.270000000000000000e+02
1.543850000000000000e+06 3.460000000000000000e+02
1.544223000000000000e+06 3.630000000000000000e+02
1.544596000000000000e+06 3.790000000000000000e+02
1.544968000000000000e+06 3.920000000000000000e+02
1.545341000000000000e+06 4.010000000000000000e+02
1.545714000000000000e+06 4.090000000000000000e+02
1.546087000000000000e+06 4.160000000000000000e+02
1.546459000000000000e+06 4.210000000000000000e+02
1.546832000000000000e+06 4.210000000000000000e+02
1.547205000000000000e+06 4.240000000000000000e+02
1.547577000000000000e+06 4.270000000000000000e+02
1.547950000000000000e+06 4.300000000000000000e+02
1.548323000000000000e+06 4.310000000000000000e+02
1.548695000000000000e+06 4.310000000000000000e+02
1.549069000000000000e+06 4.320000000000000000e+02
1.549441000000000000e+06 4.350000000000000000e+02
1.549813000000000000e+06 4.320000000000000000e+02
1.550186000000000000e+06 4.330000000000000000e+02
1.550559000000000000e+06 4.320000000000000000e+02
1.550931000000000000e+06 4.340000000000000000e+02
1.551304000000000000e+06 4.340000000000000000e+02
1.551677000000000000e+06 4.340000000000000000e+02
1.552050000000000000e+06 4.350000000000000000e+02
1.552422000000000000e+06 4.350000000000000000e+02
1.552795000000000000e+06 4.340000000000000000e+02
1.553168000000000000e+06 4.330000000000000000e+02
1.553540000000000000e+06 4.350000000000000000e+02
1.553913000000000000e+06 4.360000000000000000e+02
1.554286000000000000e+06 4.350000000000000000e+02
1.554658000000000000e+06 4.350000000000000000e+02
1.555032000000000000e+06 4.350000000000000000e+02
1.555404000000000000e+06 4.360000000000000000e+02
1.555776000000000000e+06 4.330000000000000000e+02
1.556150000000000000e+06 4.330000000000000000e+02
1.556522000000000000e+06 4.340000000000000000e+02
1.556894000000000000e+06 4.340000000000000000e+02
1.557267000000000000e+06 4.320000000000000000e+02
1.557640000000000000e+06 4.310000000000000000e+02
1.558013000000000000e+06 4.330000000000000000e+02
1.558385000000000000e+06 4.340000000000000000e+02
1.558758000000000000e+06 4.310000000000000000e+02
1.559131000000000000e+06 4.320000000000000000e+02
1.559503000000000000e+06 4.340000000000000000e+02
1.559876000000000000e+06 4.350000000000000000e+02
1.560249000000000000e+06 4.350000000000000000e+02
1.560621000000000000e+06 4.340000000000000000e+02
1.560994000000000000e+06 4.350000000000000000e+02
1.561367000000000000e+06 4.360000000000000000e+02
1.561739000000000000e+06 4.340000000000000000e+02
1.562113000000000000e+06 4.350000000000000000e+02
1.562485000000000000e+06 4.360000000000000000e+02
1.562857000000000000e+06 4.370000000000000000e+02
1.563231000000000000e+06 4.340000000000000000e+02
1.563603000000000000e+06 4.340000000000000000e+02
1.563975000000000000e+06 4.340000000000000000e+02
1.564348000000000000e+06 4.340000000000000000e+02
1.564721000000000000e+06 4.330000000000000000e+02
1.565094000000000000e+06 4.320000000000000000e+02
1.565466000000000000e+06 4.340000000000000000e+02
1.565839000000000000e+06 4.360000000000000000e+02
1.566212000000000000e+06 4.320000000000000000e+02
1.566584000000000000e+06 4.330000000000000000e+02
1.566957000000000000e+06 4.330000000000000000e+02
1.567330000000000000e+06 4.330000000000000000e+02
1.567702000000000000e+06 4.310000000000000000e+02
1.568076000000000000e+06 4.310000000000000000e+02
1.568448000000000000e+06 4.320000000000000000e+02
1.568820000000000000e+06 4.340000000000000000e+02
1.569194000000000000e+06 4.320000000000000000e+02
1.569566000000000000e+06 4.360000000000000000e+02
1.569938000000000000e+06 4.330000000000000000e+02
1.570311000000000000e+06 4.330000000000000000e+02
1.570684000000000000e+06 4.320000000000000000e+02
1.571057000000000000e+06 4.310000000000000000e+02
1.571429000000000000e+06 4.330000000000000000e+02
1.571802000000000000e+06 4.340000000000000000e+02
1.572175000000000000e+06 4.310000000000000000e+02
1.572547000000000000e+06 4.330000000000000000e+02
1.572920000000000000e+06 4.340000000000000000e+02
1.573293000000000000e+06 4.340000000000000000e+02
1.573665000000000000e+06 4.310000000000000000e+02
1.574039000000000000e+06 4.320000000000000000e+02
1.574411000000000000e+06 4.320000000000000000e+02
1.574783000000000000e+06 4.340000000000000000e+02
1.575157000000000000e+06 4.330000000000000000e+02
1.575529000000000000e+06 4.330000000000000000e+02
1.575901000000000000e+06 4.360000000000000000e+02
1.576275000000000000e+06 4.370000000000000000e+02
1.576647000000000000e+06 4.350000000000000000e+02
1.577020000000000000e+06 4.300000000000000000e+02
1.577392000000000000e+06 4.350000000000000000e+02
1.577765000000000000e+06 4.360000000000000000e+02
1.578138000000000000e+06 4.340000000000000000e+02
1.578510000000000000e+06 4.350000000000000000e+02
1.578883000000000000e+06 4.350000000000000000e+02
1.579256000000000000e+06 4.350000000000000000e+02
1.579628000000000000e+06 4.350000000000000000e+02
1.580002000000000000e+06 4.330000000000000000e+02
1.580374000000000000e+06 4.340000000000000000e+02
1.580746000000000000e+06 4.350000000000000000e+02
1.581120000000000000e+06 4.310000000000000000e+02
1.581492000000000000e+06 4.320000000000000000e+02
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

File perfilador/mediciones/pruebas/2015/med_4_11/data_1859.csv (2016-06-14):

0.000000000000000000e+00 1.000000000000000000e+01
1.540000000000000028e-04 1.000000000000000000e+01
3.109999999999999700e-04 9.000000000000000000e+00
4.659999999999999971e-04 7.000000000000000000e+00
6.239999999999999887e-04 6.000000000000000000e+00
7.789999999999999616e-04 1.000000000000000000e+01
9.370000000000000074e-04 1.300000000000000000e+01
1.091999999999999872e-03 7.000000000000000000e+00
1.248999999999999893e-03 1.000000000000000000e+01
1.403999999999999866e-03 4.000000000000000000e+00
1.562000000000000020e-03 9.000000000000000000e+00
1.716999999999999993e-03 8.000000000000000000e+00
1.874000000000000015e-03 1.000000000000000000e+01
2.030000000000000120e-03 6.000000000000000000e+00
2.186999999999999708e-03 9.000000000000000000e+00
2.341999999999999898e-03 5.000000000000000000e+00
2.500000000000000052e-03 8.000000000000000000e+00
2.654999999999999808e-03 4.000000000000000000e+00
2.811999999999999830e-03 6.000000000000000000e+00
2.967000000000000019e-03 9.000000000000000000e+00
3.124999999999999740e-03 3.000000000000000000e+00
3.279999999999999930e-03 6.000000000000000000e+00
3.436999999999999951e-03 7.000000000000000000e+00
3.591999999999999707e-03 6.000000000000000000e+00
3.749999999999999861e-03 3.000000000000000000e+00
3.904999999999999617e-03 3.000000000000000000e+00
4.062999999999999771e-03 4.000000000000000000e+00
4.217999999999999527e-03 5.000000000000000000e+00
4.374999999999999549e-03 9.000000000000000000e+00
4.530000000000000172e-03 2.000000000000000000e+00
4.687999999999999459e-03 5.000000000000000000e+00
4.843000000000000083e-03 6.000000000000000000e+00
5.000999999999999369e-03 1.000000000000000000e+00
5.154999999999999860e-03 5.000000000000000000e+00
5.313000000000000014e-03 5.000000000000000000e+00
5.467999999999999770e-03 3.000000000000000000e+00
5.625999999999999925e-03 4.000000000000000000e+00
5.780999999999999681e-03 1.000000000000000000e+00
5.937999999999999702e-03 2.000000000000000000e+00
6.092999999999999458e-03 2.000000000000000000e+00
6.250999999999999612e-03 5.000000000000000000e+00
6.405999999999999368e-03 2.000000000000000000e+00
6.562999999999999390e-03 6.000000000000000000e+00
6.718999999999999279e-03 5.000000000000000000e+00
6.875999999999999300e-03 2.000000000000000000e+00
7.030999999999999923e-03 3.000000000000000000e+00
7.189000000000000078e-03 3.000000000000000000e+00
7.343999999999999834e-03 1.000000000000000000e+00
7.500999999999999855e-03 3.000000000000000000e+00
7.655999999999999611e-03 1.000000000000000000e+00
7.813999999999999765e-03 3.000000000000000000e+00
7.969000000000000389e-03 4.000000000000000000e+00
8.126999999999998808e-03 4.000000000000000000e+00
8.281999999999999432e-03 2.000000000000000000e+00
8.439000000000000321e-03 1.000000000000000000e+00
8.593999999999999209e-03 2.000000000000000000e+00
8.751999999999999363e-03 4.000000000000000000e+00
8.906999999999999987e-03 1.000000000000000000e+00
9.063999999999999141e-03 1.000000000000000000e+00
9.218999999999999764e-03 1.000000000000000000e+00
9.376999999999999919e-03 5.000000000000000000e+00
9.531999999999998807e-03 4.000000000000000000e+00
9.688999999999999696e-03 2.000000000000000000e+00
9.844999999999999585e-03 1.000000000000000000e+00
1.000199999999999874e-02 4.000000000000000000e+00
1.015699999999999936e-02 2.000000000000000000e+00
1.031499999999999952e-02 1.000000000000000000e+00
1.047000000000000014e-02 1.000000000000000000e+00
1.062699999999999929e-02 2.000000000000000000e+00
1.078199999999999992e-02 3.000000000000000000e+00
1.094000000000000007e-02 2.000000000000000000e+00
1.109499999999999896e-02 2.000000000000000000e+00
1.125299999999999911e-02 3.000000000000000000e+00
1.140799999999999974e-02 1.000000000000000000e+00
1.156499999999999889e-02 3.000000000000000000e+00
1.171999999999999952e-02 2.000000000000000000e+00
1.187799999999999967e-02 4.000000000000000000e+00
1.203300000000000029e-02 4.000000000000000000e+00
1.218999999999999945e-02 3.000000000000000000e+00
1.234500000000000007e-02 1.000000000000000000e+00
1.250300000000000022e-02 5.000000000000000000e+00
1.265799999999999911e-02 3.000000000000000000e+00
1.281599999999999927e-02 2.000000000000000000e+00
1.297099999999999989e-02 0.000000000000000000e+00
1.312799999999999905e-02 4.000000000000000000e+00
1.328299999999999967e-02 1.000000000000000000e+00
1.344099999999999982e-02 2.000000000000000000e+00
1.359599999999999871e-02 4.000000000000000000e+00
1.375299999999999960e-02 0.000000000000000000e+00
1.390800000000000022e-02 2.000000000000000000e+00
1.406599999999999864e-02 3.000000000000000000e+00
1.422099999999999927e-02 3.000000000000000000e+00
1.437899999999999942e-02 1.000000000000000000e+00
1.453400000000000004e-02 0.000000000000000000e+00
1.469099999999999920e-02 5.000000000000000000e+00
1.484599999999999982e-02 1.000000000000000000e+00
1.500399999999999998e-02 3.000000000000000000e+00
1.515899999999999886e-02 1.000000000000000000e+00
1.531599999999999975e-02 2.000000000000000000e+00
1.547099999999999864e-02 0.000000000000000000e+00
1.562900000000000053e-02 5.000000000000000000e+00
1.578399999999999942e-02 0.000000000000000000e+00
1.594199999999999784e-02 1.000000000000000000e+00
1.609700000000000020e-02 3.000000000000000000e+00
1.625399999999999762e-02 2.000000000000000000e+00
1.640899999999999997e-02 2.000000000000000000e+00
1.656699999999999839e-02 4.000000000000000000e+00
1.672200000000000075e-02 3.000000000000000000e+00
1.687899999999999817e-02 1.000000000000000000e+00
1.703499999999999806e-02 5.000000000000000000e+00
1.719199999999999895e-02 4.000000000000000000e+00
1.734699999999999784e-02 2.000000000000000000e+00
1.750499999999999973e-02 2.000000000000000000e+00
1.765999999999999862e-02 3.000000000000000000e+00
1.781699999999999950e-02 1.000000000000000000e+00
1.797199999999999839e-02 1.000000000000000000e+00
1.813000000000000028e-02 2.000000000000000000e+00
1.828499999999999917e-02 1.000000000000000000e+00
1.844200000000000006e-02 4.000000000000000000e+00
1.859699999999999895e-02 2.000000000000000000e+00
1.875500000000000084e-02 1.000000000000000000e+00
1.890999999999999973e-02 1.000000000000000000e+00
1.906799999999999815e-02 0.000000000000000000e+00
1.922300000000000050e-02 0.000000000000000000e+00
1.937999999999999792e-02 3.000000000000000000e+00
1.953500000000000028e-02 3.000000000000000000e+00
1.969299999999999870e-02 2.000000000000000000e+00
1.984799999999999759e-02 1.000000000000000000e+00
2.000599999999999948e-02 1.000000000000000000e+00
2.016099999999999837e-02 3.000000000000000000e+00
2.031799999999999926e-02 3.000000000000000000e+00
2.047299999999999814e-02 2.000000000000000000e+00
2.063100000000000003e-02 2.000000000000000000e+00
2.078599999999999892e-02 1.000000000000000000e+00
2.094299999999999981e-02 4.000000000000000000e+00
2.109799999999999870e-02 4.000000000000000000e+00
2.125600000000000059e-02 1.000000000000000000e+00
2.141099999999999948e-02 2.000000000000000000e+00
2.156800000000000037e-02 2.000000000000000000e+00
2.172400000000000025e-02 1.000000000000000000e+00
2.188099999999999767e-02 4.000000000000000000e+00
2.203600000000000003e-02 2.000000000000000000e+00
2.219399999999999845e-02 2.000000000000000000e+00
2.234899999999999734e-02 1.000000000000000000e+00
2.250599999999999823e-02 4.000000000000000000e+00
2.266100000000000059e-02 2.000000000000000000e+00
2.281899999999999901e-02 3.000000000000000000e+00
2.297399999999999790e-02 1.000000000000000000e+00
2.313199999999999978e-02 3.000000000000000000e+00
2.328699999999999867e-02 4.000000000000000000e+00
2.344399999999999956e-02 2.000000000000000000e+00
2.359899999999999845e-02 3.000000000000000000e+00
2.375700000000000034e-02 5.000000000000000000e+00
2.391199999999999923e-02 3.000000000000000000e+00
2.406900000000000012e-02 0.000000000000000000e+00
2.422399999999999901e-02 1.000000000000000000e+00
2.438199999999999742e-02 4.000000000000000000e+00
2.453699999999999978e-02 4.000000000000000000e+00
2.469399999999999720e-02 5.000000000000000000e+00
2.485000000000000056e-02 1.000000000000000000e+00
2.500699999999999798e-02 1.000000000000000000e+00
2.516200000000000034e-02 4.000000000000000000e+00
2.531999999999999876e-02 1.000000000000000000e+00
2.547499999999999765e-02 3.000000000000000000e+00
2.563199999999999854e-02 2.000000000000000000e+00
2.578699999999999742e-02 2.000000000000000000e+00
2.594499999999999931e-02 2.000000000000000000e+00
2.609999999999999820e-02 3.000000000000000000e+00
2.625800000000000009e-02 4.000000000000000000e+00
2.641299999999999898e-02 3.000000000000000000e+00
2.656999999999999987e-02 4.000000000000000000e+00
2.672499999999999876e-02 4.000000000000000000e+00
2.688299999999999718e-02 5.000000000000000000e+00
2.703799999999999953e-02 5.000000000000000000e+00
2.719500000000000042e-02 4.000000000000000000e+00
2.734999999999999931e-02 4.000000000000000000e+00
2.750799999999999773e-02 1.000000000000000000e+01
2.766300000000000009e-02 4.000000000000000000e+00
2.782099999999999851e-02 5.000000000000000000e+00
2.797599999999999740e-02 4.000000000000000000e+00
2.813299999999999829e-02 8.000000000000000000e+00
2.828799999999999717e-02 7.000000000000000000e+00
2.844599999999999906e-02 1.100000000000000000e+01
2.860099999999999795e-02 8.000000000000000000e+00
2.875799999999999884e-02 9.000000000000000000e+00
2.891299999999999773e-02 9.000000000000000000e+00
2.907099999999999962e-02 1.300000000000000000e+01
2.922599999999999851e-02 6.000000000000000000e+00
2.938400000000000040e-02 1.600000000000000000e+01
2.953899999999999929e-02 1.300000000000000000e+01
2.969600000000000017e-02 1.100000000000000000e+01
2.985099999999999906e-02 1.600000000000000000e+01
3.000899999999999748e-02 1.400000000000000000e+01
3.016399999999999984e-02 1.300000000000000000e+01
3.032099999999999726e-02 1.900000000000000000e+01
3.047599999999999962e-02 1.400000000000000000e+01
3.063399999999999804e-02 1.900000000000000000e+01
3.078899999999999693e-02 1.900000000000000000e+01
3.094699999999999881e-02 2.200000000000000000e+01
3.110199999999999770e-02 2.400000000000000000e+01
3.125899999999999512e-02 2.500000000000000000e+01
3.141399999999999748e-02 2.900000000000000000e+01
3.157199999999999590e-02 3.300000000000000000e+01
3.172699999999999826e-02 3.500000000000000000e+01
3.188399999999999568e-02 4.800000000000000000e+01
3.203999999999999904e-02 5.200000000000000000e+01
3.219699999999999646e-02 6.300000000000000000e+01
3.235199999999999881e-02 6.800000000000000000e+01
3.250999999999999723e-02 7.600000000000000000e+01
3.266499999999999959e-02 7.700000000000000000e+01
3.282199999999999701e-02 8.000000000000000000e+01
3.297699999999999937e-02 8.300000000000000000e+01
3.313499999999999779e-02 8.500000000000000000e+01
3.329000000000000015e-02 8.800000000000000000e+01
3.344699999999999757e-02 8.700000000000000000e+01
3.360199999999999992e-02 8.700000000000000000e+01
3.375999999999999834e-02 8.900000000000000000e+01
3.391500000000000070e-02 8.700000000000000000e+01
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

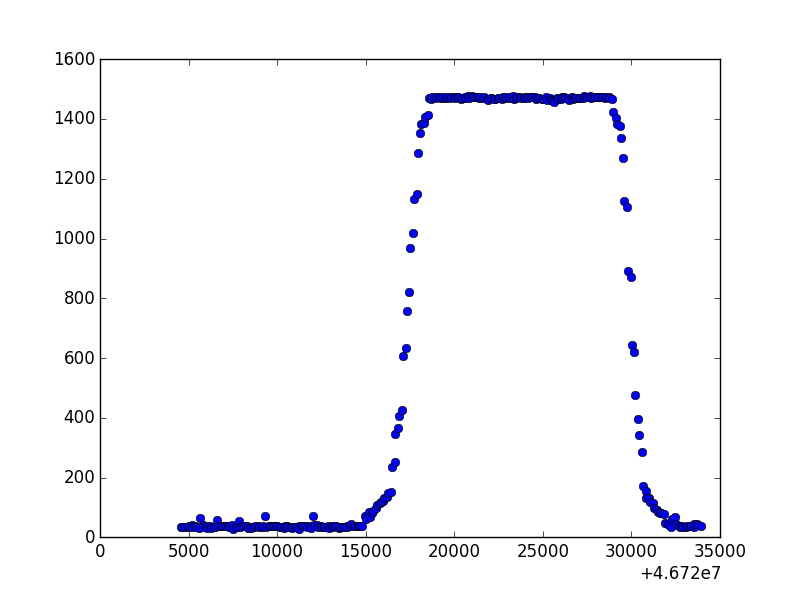
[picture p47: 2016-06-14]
perfilador/mediciones/pruebas/2015/med_20_10/data_19_46_rec1.png

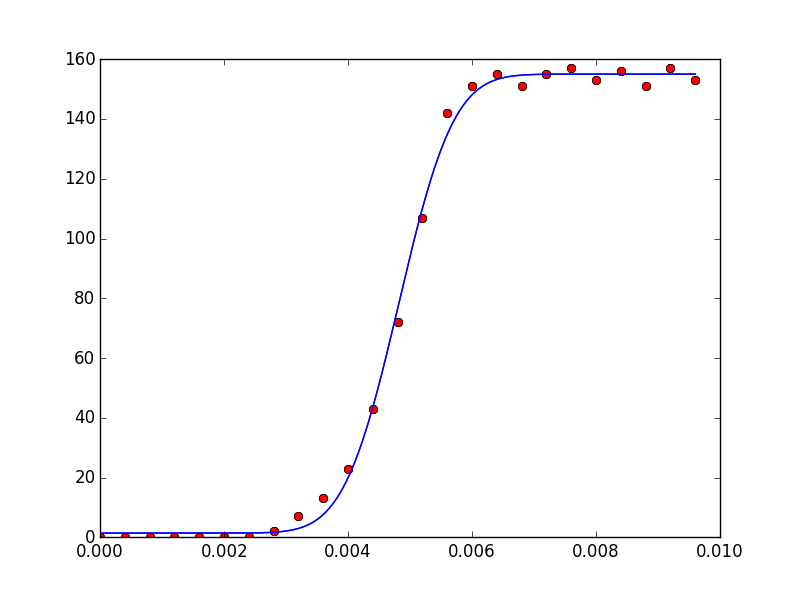
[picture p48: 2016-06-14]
perfilador/mediciones/pruebas/2015/med_6_10/figure_1.png

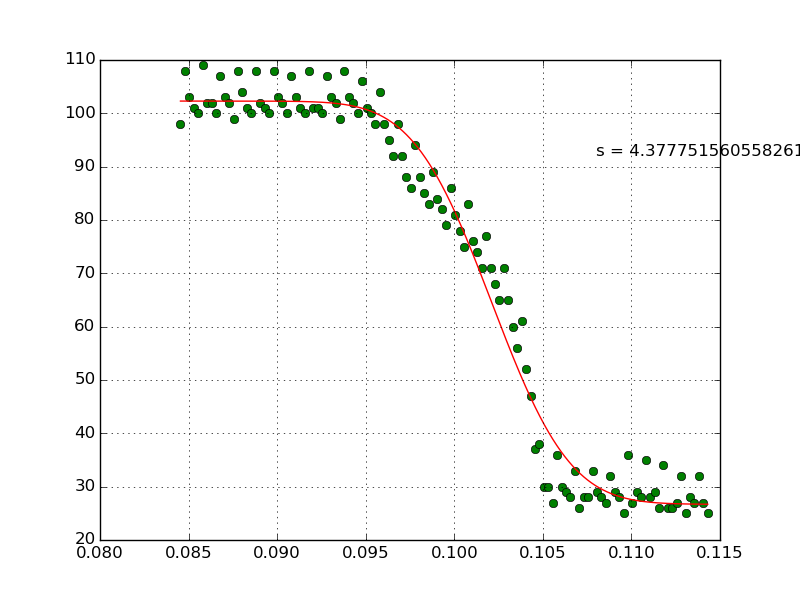
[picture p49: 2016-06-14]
perfilador/mediciones/pruebas/2015/med_4_11/data_1752_out.png

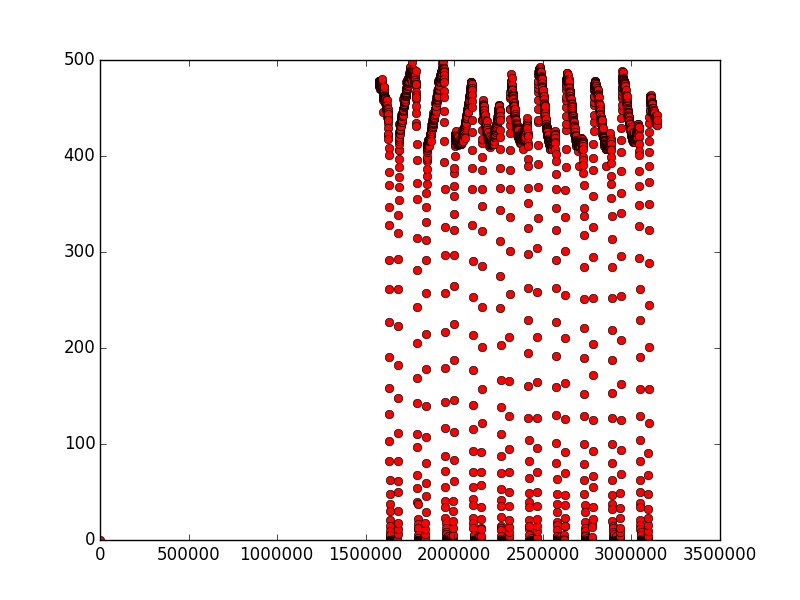
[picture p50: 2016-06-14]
perfilador/mediciones/pruebas/2015/med_13_10/data_13_10_15.png

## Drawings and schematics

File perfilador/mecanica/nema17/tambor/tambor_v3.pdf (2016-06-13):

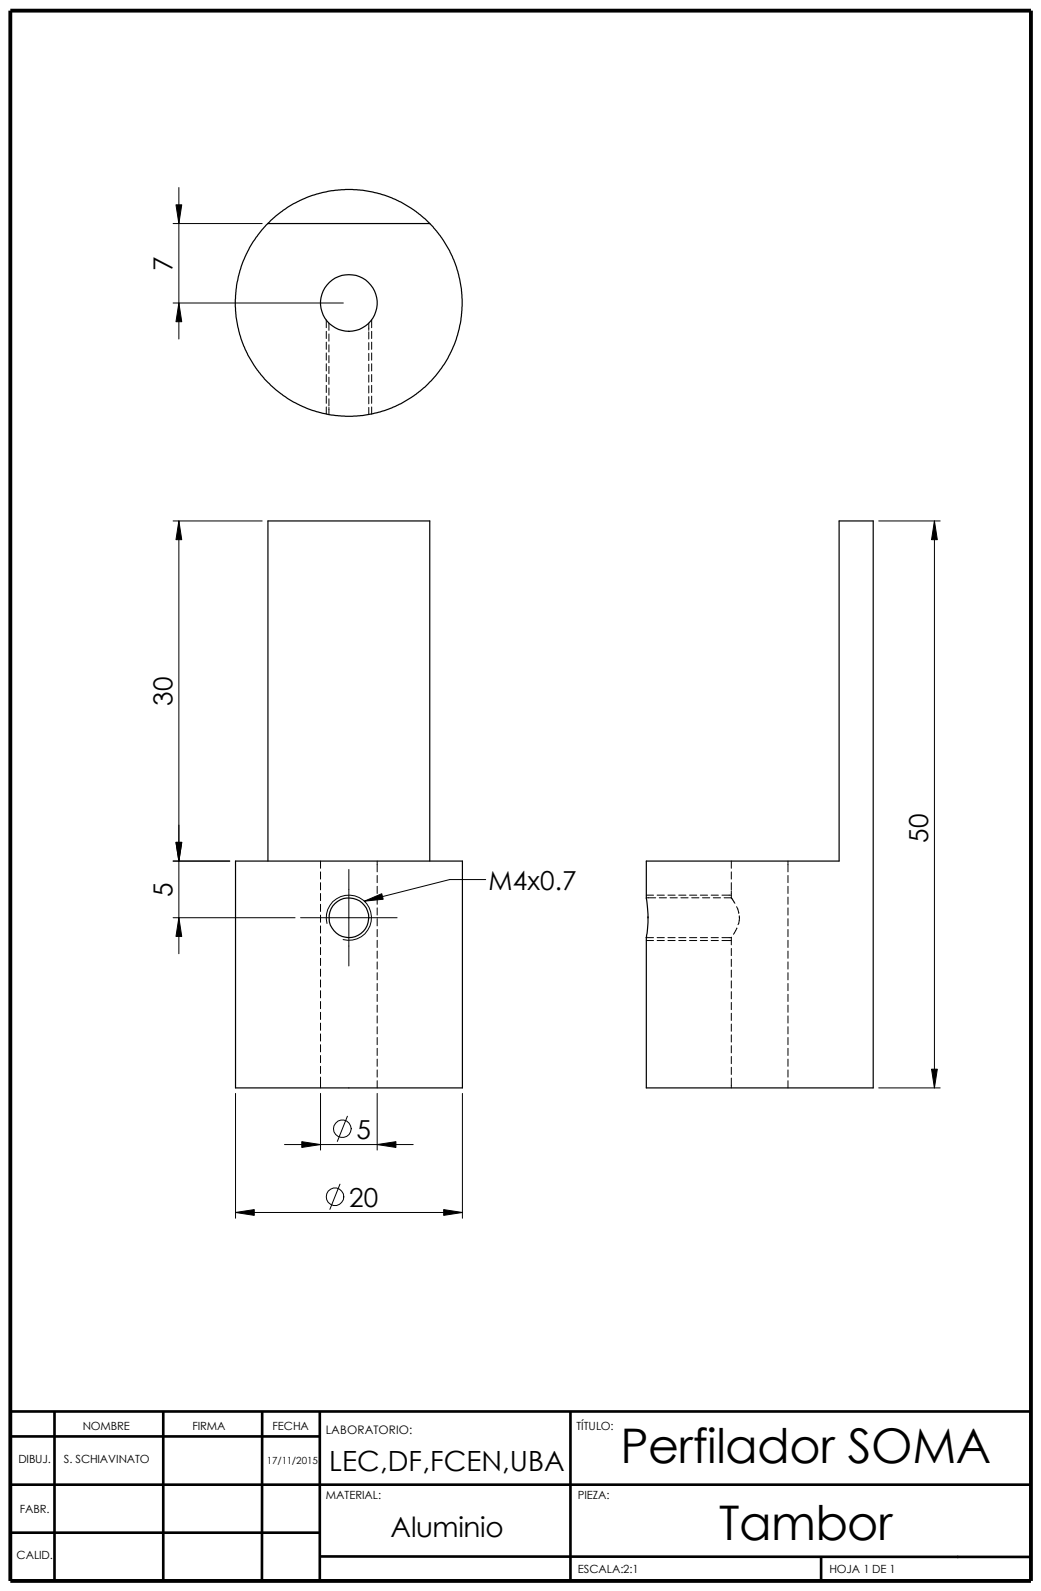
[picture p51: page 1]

NOMBRE | FIRMA | FECHA | LABORATORIO: LEC,DF,FCEN,UBA | TÍTULO: Perfilador SOMA
DIBUJ. | S. SCHIAVINATO | | 17/11/2015

FABR. | | | | MATERIAL: Aluminio | PIEZA: Tambor

CALID.

ESCALA:2:1 | HOJA 1 DE 1

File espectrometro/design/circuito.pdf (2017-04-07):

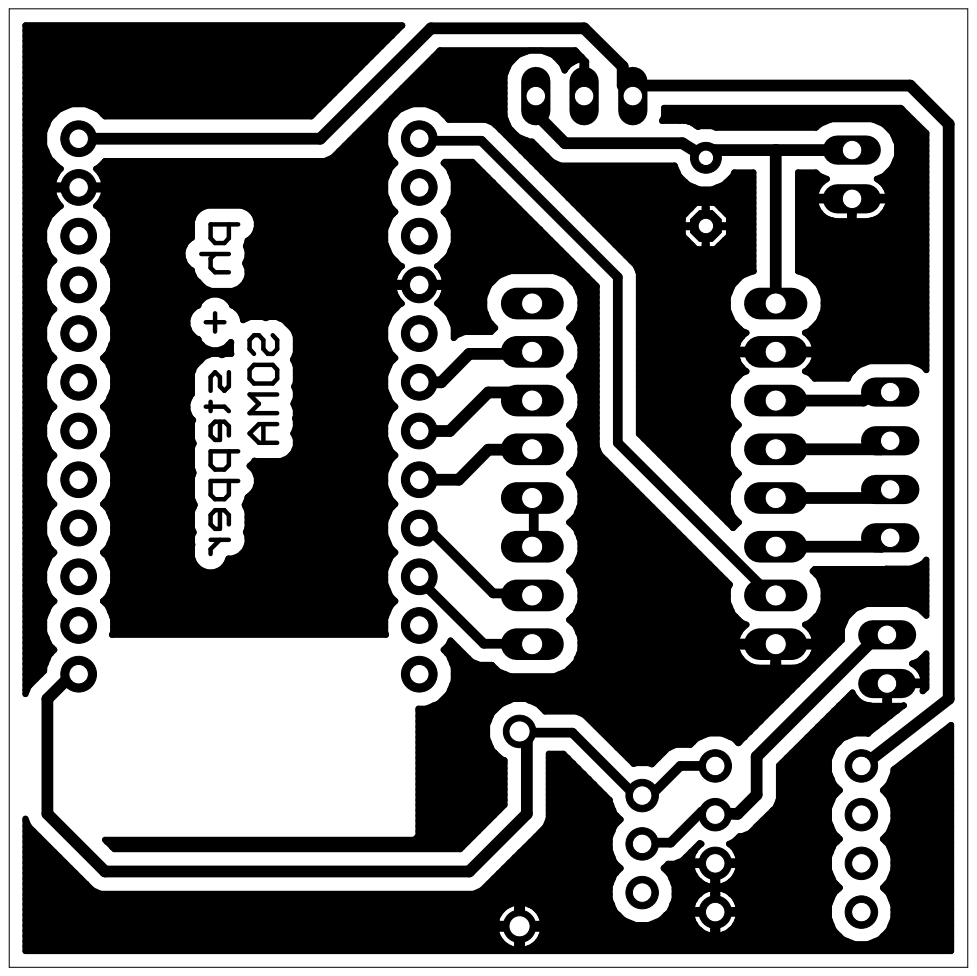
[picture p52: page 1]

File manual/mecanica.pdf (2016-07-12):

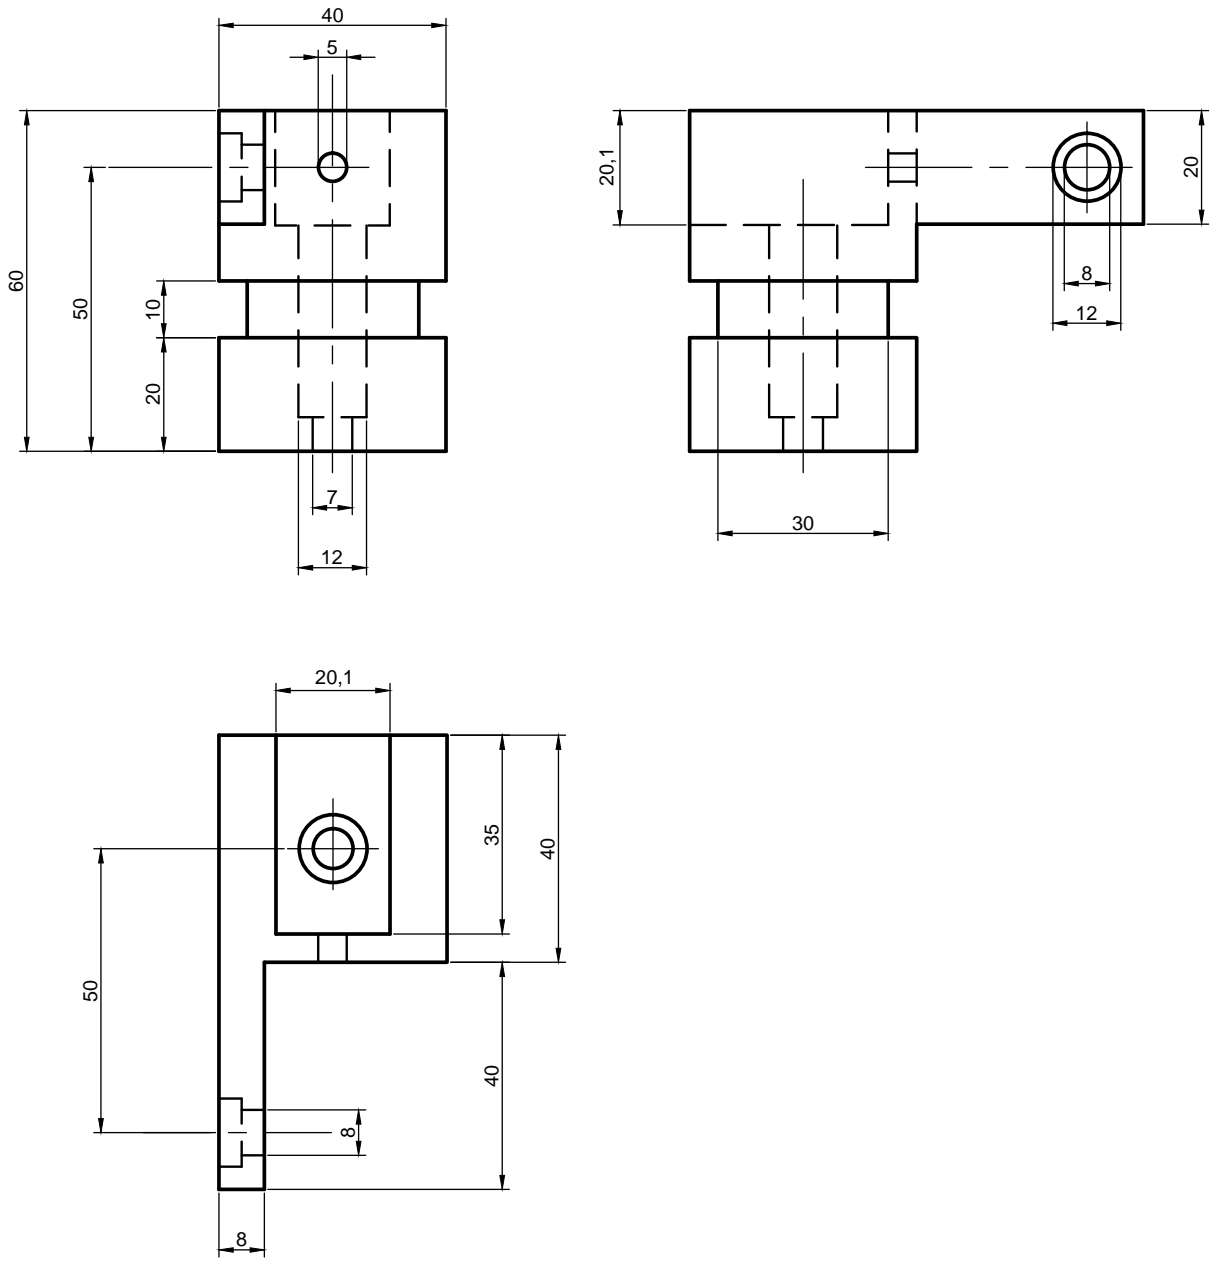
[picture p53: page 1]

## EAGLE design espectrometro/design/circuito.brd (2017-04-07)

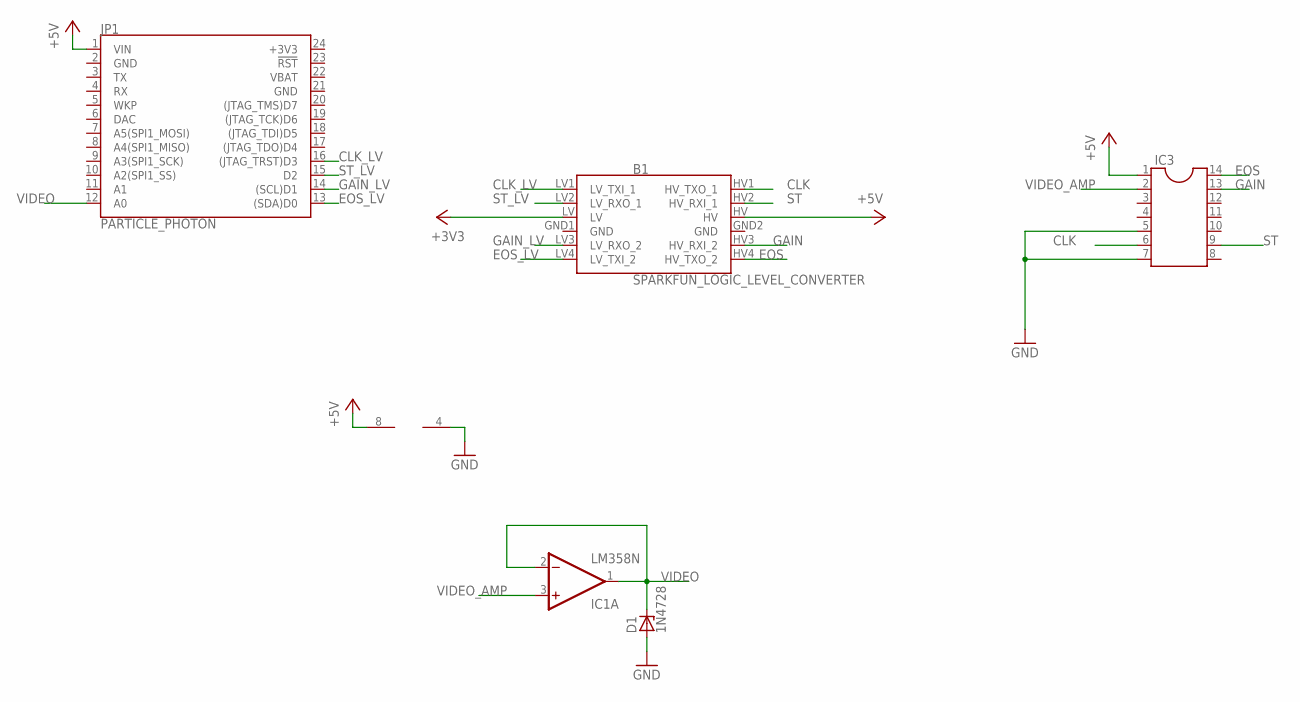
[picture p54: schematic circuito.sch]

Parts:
B1: SPARKFUN_LOGIC_LEVEL_CONVERTER
D1: 1N4728; DO41Z10
IC1: LM358N; DIL08
IC3: DIL14S; SOCKET-14
JP1: PARTICLE_PHOTON

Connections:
+3V3: B1.LV, JP1.24 (+3V3)
+5V: B1.HV, IC1.8 (V+), IC3.1, JP1.1 (VIN)
CLK: B1.HV1 (HV_TXO_1), IC3.6
CLK_LV: B1.LV1 (LV_TXI_1), JP1.16 ((JTAG_TRST)D3)
EOS: B1.HV4 (HV_TXO_2), IC3.14
EOS_LV: B1.LV4 (LV_TXI_2), JP1.13 ((SDA)D0)
GAIN: B1.HV3 (HV_RXI_2), IC3.13
GAIN_LV: B1.LV3 (LV_RXO_2), JP1.14 ((SCL)D1)
GND: B1.GND1 (GND), B1.GND2 (GND), D1.A, IC1.4 (V-), IC3.5, IC3.7, JP1.2 (GND), JP1.21 (GND)
ST: B1.HV2 (HV_RXI_1), IC3.9
ST_LV: B1.LV2 (LV_RXO_1), JP1.15 (D2)
VBAT: JP1.22 (VBAT)
VIDEO: D1.C, IC1.1 (OUT), IC1.2 (-IN), JP1.12 (A0)
VIDEO_AMP: IC1.3 (+IN), IC3.2

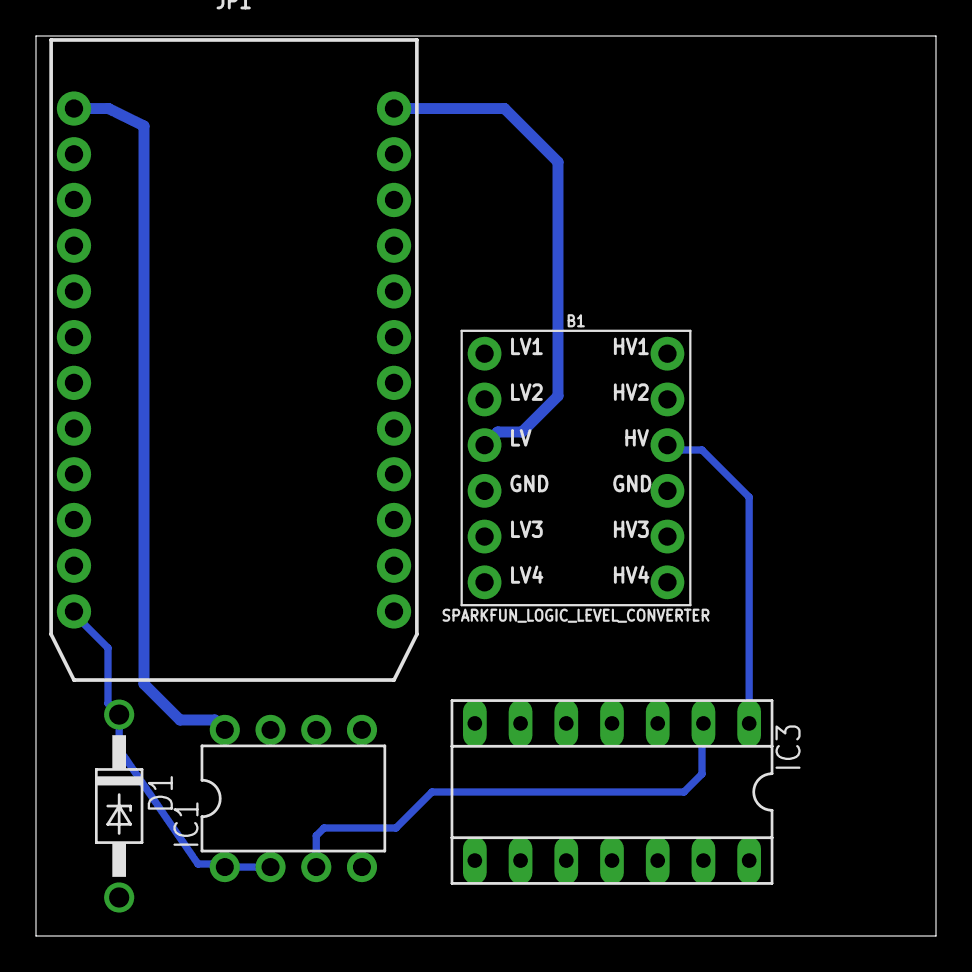
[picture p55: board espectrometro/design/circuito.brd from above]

Board: 2 copper layers, 50.0 x 50.0 mm, 5 parts (0 on the bottom side), 13 nets.

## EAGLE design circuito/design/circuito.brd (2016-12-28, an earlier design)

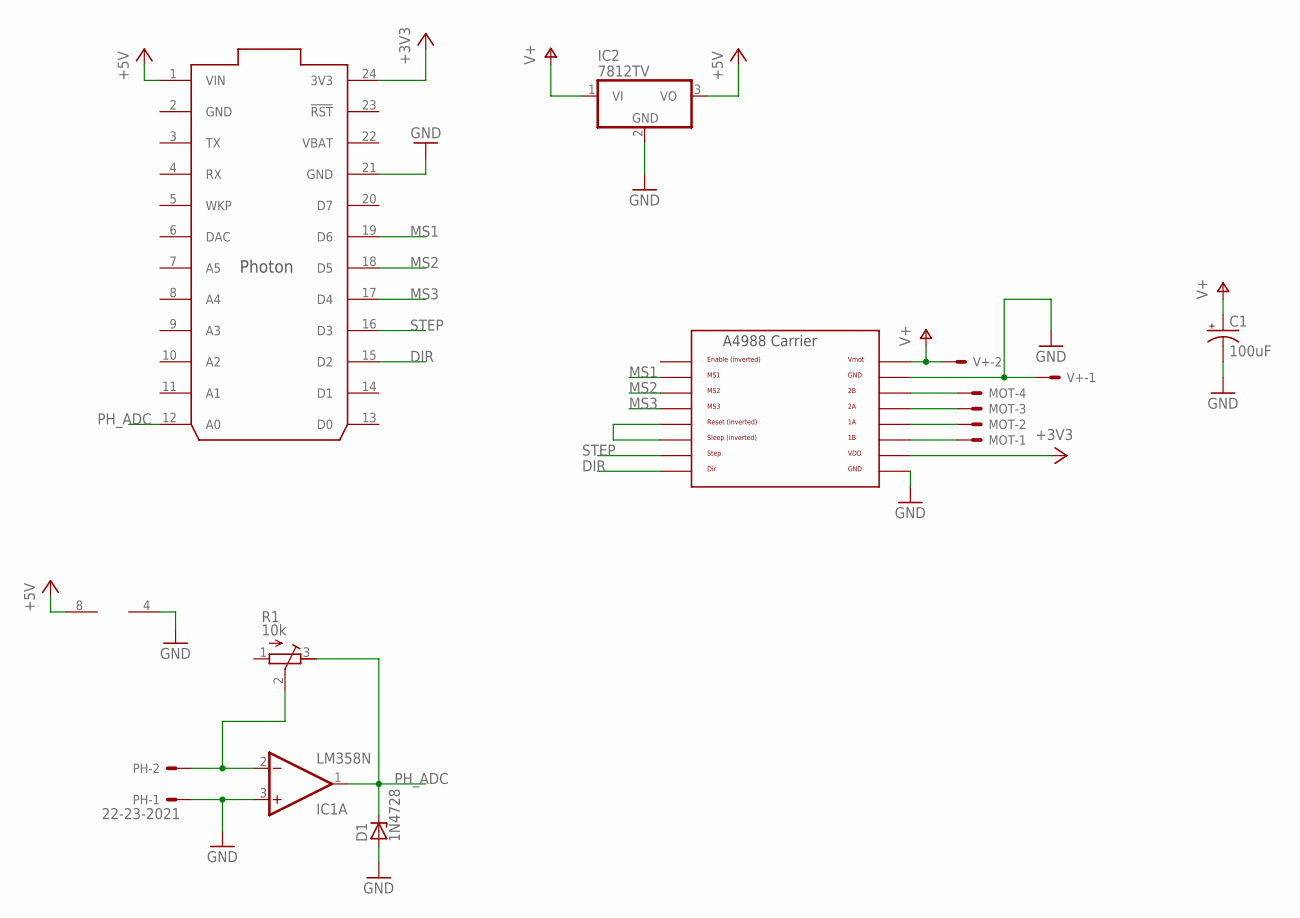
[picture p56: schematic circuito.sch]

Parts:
C1: 100uF; E3,5-8
D1: 1N4728; DO41Z10
IC1: LM358N; DIL08
IC2: 7812TV; TO220V
MOT: 22-23-2041
PH: 22-23-2021
R1: 10k; RTRIM64W
U$1: PHOTON_WITH_HEADERS; PHOTON
U$2: A4988BREAKOUT
V+: 22-23-2021

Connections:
+3V3: U$1.24 (3V3), U$2.VDD
+5V: IC1.8 (V+), IC2.3 (VO), U$1.1 (VIN)
DIR: U$1.15 (D2), U$2.DIR
GND: C1.-, D1.A, IC1.3 (+IN), IC1.4 (V-), IC2.2 (GND), PH.1, U$1.2 (GND), U$1.21 (GND), U$2.GND, U$2.GND@0 (GND), V+.1
MS1: U$1.19 (D6), U$2.MS1
MS2: U$1.18 (D5), U$2.MS2
MS3: U$1.17 (D4), U$2.MS3
unnamed: MOT.4, U$2.2B
unnamed: U$2.RST, U$2.SLP (SLEEP)
unnamed: MOT.1, U$2.1B
unnamed: MOT.2, U$2.1A
unnamed: MOT.3, U$2.2A
unnamed: IC1.2 (-IN), PH.2, R1.2 (S)
PH_ADC: D1.C, IC1.1 (OUT), R1.3 (E), U$1.12 (A0)
STEP: U$1.16 (D3), U$2.STEP
V+: C1.+, IC2.1 (VI), U$2.VMOT, V+.2
VBAT: U$1.22 (VBAT)

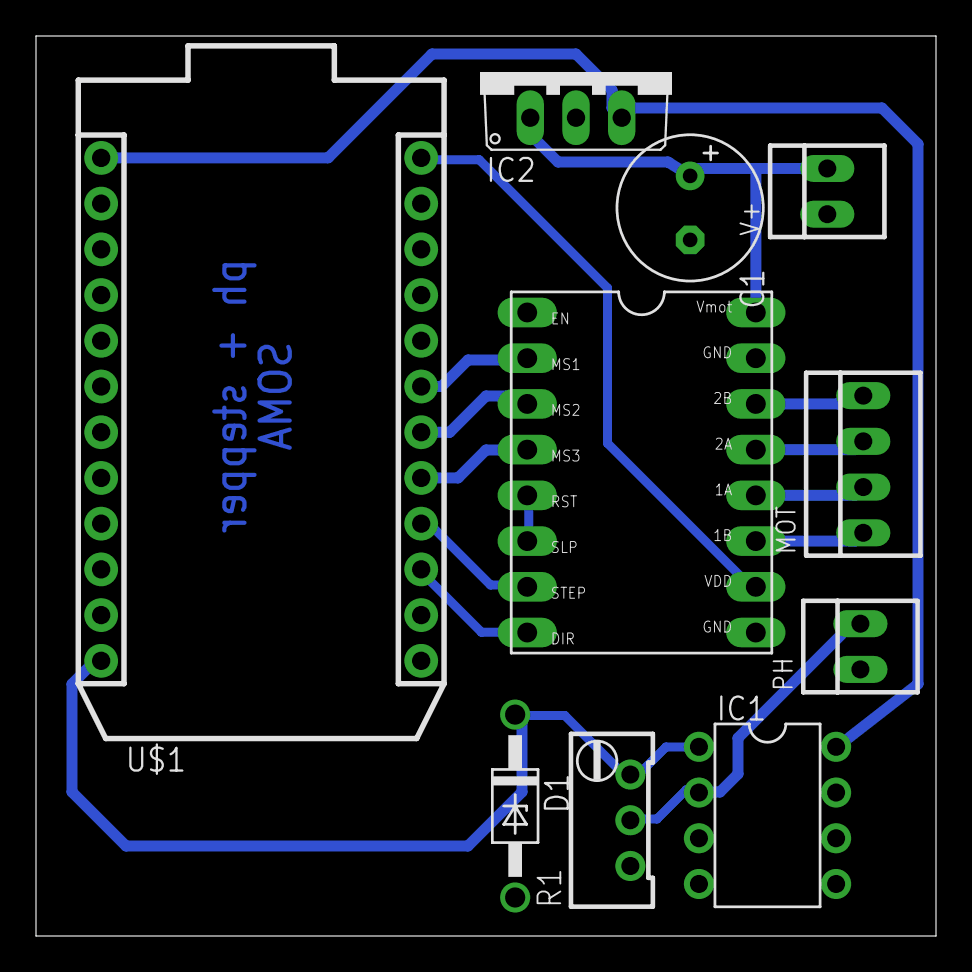
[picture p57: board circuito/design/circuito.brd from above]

Board: 2 copper layers, 50.0 x 50.0 mm, 10 parts (0 on the bottom side), 16 nets.

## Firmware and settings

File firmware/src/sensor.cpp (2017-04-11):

#include "application.h"

#define PORT 7662
#define OLED 0 //Uso del OLED

//Modo manual

//System.disable(SYSTEM_FLAG_RESET_NETWORK_ON_CLOUD_ERRORS);


#define WIFI 1  //Uso del WiFi
#define CLOUD 0 //Uso de Cloud
#define SSID "WiFi-LEC"
#define PASS "coefilec"
String ip;

#if CLOUD == 0
	SYSTEM_MODE(MANUAL);
#endif

#define SENSOR 0 //0 => Perfilador, 1 => Polarizador
#if SENSOR == 0
#define SPEED 6000
#else
#define SPEED 2000
#endif


//Server telnet
TCPServer server = TCPServer(PORT);
TCPClient client;

//Variables para mediciones
#define N_MED 4000

//Pines para el motor y el ADC
#define STEPPER_DIR_PIN D0
#define STEPPER_STEP_PIN D1
#define SENSOR_PIN A0

class Sensor {
	public:
			unsigned int x[N_MED];
			unsigned int y[N_MED];

			Sensor() {
			    pinMode(STEPPER_DIR_PIN, OUTPUT);
			    pinMode(STEPPER_STEP_PIN, OUTPUT);

			    digitalWrite(STEPPER_DIR_PIN, HIGH);
			    for (int i = 0; i < SPEED; i+=10){
				    analogWrite(STEPPER_STEP_PIN, 128, i);
				    delay(5);
			    }

			}

        void measure() {
		      attachInterrupt(STEPPER_STEP_PIN, &Sensor::countStep, this, RISING);
          delay(N_MED/SPEED);
        }

	private:
		volatile int step = 0;
		void countStep(){
			if (step == N_MED) {
        			step = 0;
              detachInterrupt(STEPPER_STEP_PIN);
    			}
    			else {
              x[step] = step;
              y[step] = analogRead(SENSOR_PIN);
        			step++;
    			}
		}

};

Sensor sens;  //Construyo el sensor, inicializa el motor

void setup() {

  //Clientes
  server.begin();
  Serial.begin(9600);

  //ADC speed
  setADCSampleTime(ADC_SampleTime_3Cycles);

  //Configuro WiFi
	#if WIFI == 1
		if (WiFi.clearCredentials()){
			RGB.control(true);
		  RGB.color(255,0,0);
			WiFi.on();
			WiFi.setCredentials(SSID, PASS);
			WiFi.useDynamicIP();
	    WiFi.connect();
			while (!WiFi.ready()){ }

			ip = String(WiFi.localIP());

			#if CLOUD == 1
				Particle.variable("ip", ip);
			#endif

			RGB.color(0,255,0);
		}
	#endif
}

//Variables para imprimir IP por puerto serie
int prevT = 0;
int deltaT = 1000;


void loop() {

    //Devuelvo la IP
    int currT = millis();
  	if (currT - prevT > deltaT) {
    	Serial.print("Ip: ");
    	Serial.println(WiFi.localIP());
			prevT = currT;
		}

    if (client.connected()) {

      //Recién ahora que me piden, mido
      sens.measure();

      //Mando al cliente que escucha en el servidor
      for (int i = 0; i < N_MED; i++){
        client.print(sens.x[i]);
        client.print(";");
        client.println(sens.y[i]);
      }
      //Fin de transmisión
      client.print("END");
      client.stop();

    }
    else {
      client = server.available();
    }
}

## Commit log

2016-06-13 Se copia desarrollo del GDrive
    [_lin_amp.csv, bearing.scad, calibracion_x.csv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]
2016-06-13 Se agrega mediciones, más o menos ordenadas. Se cambia README
    [100uA_chop.csv, 12rmp_din.csv, 12rps.csv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]
2016-06-15 Medición con tambor de plástico
    [plastico_15_5.csv]
2016-06-15 Nueva iteración, agujero más grande
    [soporte.scad]
2016-06-15 Cambios de script menores, nueva medición
2016-06-16 Cambios de gitignore para windows
2016-06-16 Se elimina archivos de thumbnails de windows
2016-06-16 Nueva iteración de soporte
    [soporte.scad]
2016-06-16 Carcasa final. Va con un acrilico arriba
    [carcasa.scad]
2016-06-18 Imagenes para presentación. Nuevos cambios en modelo
    [soporte.scad]
2016-06-23 Se ordenaron archivos, se creó nuevo archivo de diseño para polarimetro
    [_lin_amp.csv, eje.stl, engranaje_motor.stl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]
2016-06-24 Cambios del engranaje. Agregado mejor interfaz web. Cambio en código de sketch, ahora es compatible con polarimetro
    [engranajes.scad, engranajes.stl, soporte.scad]
2016-06-30 Nuevo cambio en carcaza
    [carcasa.scad, carcasa.stl]
2016-06-30 Se cambio velocidad para polarimetro
2016-06-30 Cambios de diseño.
    [soporte.STL, soporte.scad, soporte.stl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]
2016-06-30 Mediciones sin ruido finales. Polarización definida
    [pol_fibra_sin_ruido.csv, pol_laser_sin_ruido.csv]
2016-06-30 Implementación con PyQT en progreso
    [prueba.csv]
2016-07-01 Se agrega etiquetas del preprocesador para usar polarimetro y perfilador en la compilación
    [carcaza.STL]
2016-07-01 Ajustes hechos para datos nuevos
2016-07-01 Commit de charla
2016-07-01 Datos viejos agregados
    [pol_fibra.csv, pol_laser.csv]
2016-07-01 Medición de spim con plástico PLA
    [spim_riel_plastico.csv]
2016-07-01 Mediciones de diferentes laseres, azul y verde
    [pol_fibra_azul_alta_p.csv, pol_fibra_azul_alta_p_2.csv, pol_fibra_azul_baja_p.csv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]
2016-07-01 Cambio de titulo de la charla
2016-07-04 Primer iteración de charla final labo 7
    [pol_fibra_rojo.csv, pol_fibra_rojo_sin_ruido.csv, pol_laser_sin_ruido.csv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]
2016-07-05 Segunda iteración y presentación de charla final labo 7
    [pol_fibra_azul_baja_p.csv]
2016-07-12 Nuevos diseños, más archivos dwg/dxf con planos mecánicos
    [engranajes.scad, engranajes.stl, polarimetro.scad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]
2016-07-12 Cambios en mediciones de perfil
    [calibracion_y.csv]
2016-07-15 Cambio final del circuito.
    [sensor.sch]
2016-07-15 Reordenado de archivos de informes. Anteúltima iteración del informe final.
    [engranaje_mayor_polarimetro.dwg, engranaje_mayor_polarimetro.dxf, perfilador.scad]
2016-07-16 Nueva iteración del informe. Preprint
    [perfilador.scad, polarimetro.scad, soporte.scad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]
2016-07-19 Iteración final del informe
    [carcasa.scad]
2016-09-12 Cambio menor de gui
2016-09-12 Cambios menores
    [carcasa.scad]
2016-09-13 Primer commit de documentación
2016-09-13 Se comprime charla final de laboratorio 7
2016-09-13 Archivos de charla final
2016-09-13 Se comprime archivos de informe de laboratorio 7
2016-10-11 Circuito funcionando, imprime IP por puerto serie
2016-10-11 Última iteración
    [carcasa.scad, carcasa.stl, engranajes.scad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]
2016-10-23 Sensores funcionando con ip dinámica
2016-11-08 Implementación con 7805
    [sensor.kicad_pcb, sensor.sch]
2016-12-28 Mejora en interfaz, redescubrimiento de sensor en segmento de red
2016-12-28 Esquemático en formato EAGLE
    [circuito.brd, circuito.sch, sensor.kicad_pcb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]
2017-01-01 Uso de web workers para interfaz web
2017-01-01 Uso de IP en Cloud, a nivel uC
2017-01-01 Cambio de código
2017-04-07 Ordenado de archivos
2017-04-07 PDF de ph+motor
2017-04-07 Cambios en makefile, usa node local. Cambios de código
2017-04-07 Diseño de espectrometro
    [circuito.brd, circuito.sch]
2017-04-10 Ordenado de adquisición
    [pol_fibra_azul_baja_p.csv, prueba.csv]
2017-04-11 Ordenado de web y mejora de esta. Se puede setear la IP
    [prueba.csv]
2017-04-11 Reordenado de firmware. Compila y funciona
2017-04-11 Mejora del README con el reordenado. Mas docs

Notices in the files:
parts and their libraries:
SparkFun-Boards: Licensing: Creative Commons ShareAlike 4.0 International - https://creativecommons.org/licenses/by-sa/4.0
